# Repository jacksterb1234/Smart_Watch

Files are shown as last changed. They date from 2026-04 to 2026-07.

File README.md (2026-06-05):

# Smart Watch — Custom KiCad Smartwatch PCB

A fully custom smartwatch designed from the ground up, featuring a purpose-built PCB, BLE connectivity, and a 3D-printed case. Designed for complete control over hardware and software integration.

> Integration testing projected to begin July 2026.

## Features

- **MCU:** Nordic nRF54L15 — ultra-low power with integrated Bluetooth LE
- **Step counting** via IMU
- **Heart rate sensing**
- **Touchscreen display**
- **Music control** and **notification vibration** (haptic)
- **USB-C charging**
- **Custom 3D-printed case** — ~30% lighter than off-the-shelf alternatives, fully personalizable
- Designed for **JLCPCB assembly**

## Repository Structure

```
Smart_Watch/
├── Architecture.kicad_sch   # Top-level architecture schematic
├── MCU.kicad_sch            # nRF54L15 MCU schematic
├── Power.kicad_sch          # Power management schematic
├── Peripherals.kicad_sch   # Sensors & peripheral schematic
├── Smart_Watch.kicad_pcb   # PCB layout
├── Smart_Watch.pdf          # Full schematic export
├── Smart_Watch.pretty/     # Custom KiCad footprints
├── Smart_Watch.3dshapes/   # 3D models for PCB components
├── ZIF.pretty/              # ZIF connector footprints
├── B2B_PH_SM4_TB/          # Board-to-board connector footprints
├── Backpack_Board/         # Backpack extension board
├── Case/                   # 3D-printable case files
└── jlcpcb/                  # JLCPCB production files (Gerbers, BOM, CPL)
```

## Tools Used

- **KiCad** — Schematic capture and PCB layout
- **JLCPCB** — PCB fabrication and SMT assembly
- **SolidWorks / Fusion360** — Case design

## Key Components

| Component | Function |
|---|---|
| nRF54L15 | MCU with integrated BLE |
| Heart rate sensor | Optical heart rate monitoring |
| IMU | Step counting and motion sensing |
| Touchscreen | User interface display |
| USB-C charger IC | Battery charging via USB-C |

## Author

**Jackson Barber** — [github.com/jacksterb1234](https://github.com/jacksterb1234)

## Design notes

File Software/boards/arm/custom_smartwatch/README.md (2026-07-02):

# Custom Smartwatch Board

Initial Zephyr board definition for the NORA-B106 / nRF5340 application core.
Pin mappings use the local KiCad NORA-B106 symbol and preserve the same
schematic net distribution used before the module swap.

Build from the application root with the NCS v3.3.1 toolchain environment:

```powershell
$tc = 'C:\ncs\toolchains\936afb6332'
$env:PATH = "$tc;$tc\mingw64\bin;$tc\bin;$tc\opt\bin;$tc\opt\bin\Scripts;$tc\opt\nanopb\generator-bin;$tc\nrfutil\bin;$tc\opt\zephyr-sdk\arm-zephyr-eabi\bin;$tc\opt\zephyr-sdk\riscv64-zephyr-elf\bin;$env:PATH"
$env:PYTHONPATH = "$tc\opt\bin;$tc\opt\bin\Lib;$tc\opt\bin\Lib\site-packages"
$env:NRFUTIL_HOME = "$tc\nrfutil\home"
$env:ZEPHYR_TOOLCHAIN_VARIANT = 'zephyr'
$env:ZEPHYR_SDK_INSTALL_DIR = "$tc\opt\zephyr-sdk"
$env:ZEPHYR_BASE = 'C:\ncs\v3.3.1\zephyr'
west build --sysbuild -b custom_smartwatch/nrf5340/cpuapp -- -DBOARD_ROOT="$PWD"
```

Track bring-up and product readiness in the
[firmware readiness checklist](../../../docs/firmware_readiness_checklist.md).

The board currently enables the main I2C bus, nPM1300, BMI270, LPS22DF, four
buttons, GC9A01 display SPI, W25Q32 QSPI flash, FAN5622 backlight GPIO, and
DRV2603 haptic PWM/enable pins where Zephyr has suitable upstream bindings. The
sysbuild path also builds the nRF5340 network-core `ipc_radio` image for BLE
HCI IPC.

The nPM1300 charger profile is configured for a single-cell LiPo with 4.2 V
termination, 200 mA charge current, 3.7 V nominal voltage, and no thermistor.

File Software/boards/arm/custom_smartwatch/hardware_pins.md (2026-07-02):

# Custom Smartwatch Pin Ledger

This ledger records schematic net names against NORA-B106 module pads and the
local KiCad NORA-B106 symbol GPIO mapping.

## Blocking Checks

- Per user direction, the main I2C routing is corrected. Firmware maps NORA pad
  `A3` / `P1.03` as SCL and pad `B4` / `P1.02` as SDA.
- MAX30102 is represented on I2C at `0x57` using Zephyr's upstream
  `maxim,max30101` red/IR driver path. Its active-low interrupt net is on
  `P0.21`.

## Main I2C

| Signal | NORA pad | nRF5340 GPIO | Zephyr pinctrl |
| --- | --- | --- | --- |
| `SCL` | `A3` | `P1.03` | `NRF_PSEL(TWIM_SCL, 1, 3)` |
| `SDA` | `B4` | `P1.02` | `NRF_PSEL(TWIM_SDA, 1, 2)` |

Shared by BMI270, MAX30102, LPS22DF, nPM1300, and display touch I2C.

## Interrupts

| Net | NORA pad | nRF5340 GPIO | Firmware status |
| --- | --- | --- | --- |
| `PMIC_INT` | `H1` | `P0.24` | Enabled |
| `BMI_INT` | `C8` | `P0.22` | Enabled |
| `MAX_INT` | `E3` | `P0.21` | Enabled via MAX30101-compatible driver |
| `LPS_INT` | `A5` | `P0.20` | Enabled |

## Buttons

All buttons are active-low to ground and should use pull-ups.

| Switch | Net | NORA pad | nRF5340 GPIO |
| --- | --- | --- | --- |
| `SW4` | `BTN_1` | `G2` | `P0.26` |
| `SW5` | `BTN_2` | `B5` | `P0.03` |
| `SW6` | `BTN_3` | `A4` | `P1.00` |
| `SW7` | `BTN_4` | `F8` | `P1.14` |

## Display SPI And Control

| Net | NORA pad | nRF5340 GPIO |
| --- | --- | --- |
| `DISPLAY_CS` | `A2` | `P0.12` |
| `DISPLAY_CLK` | `B3` | `P0.11` |
| `DISPLAY_DATA` | `C1` | `P0.10` |
| `DISPLAY_DC` | `C2` | `P0.09` |
| `DISPLAY_RST` | `J9` | `P0.31` |

## Display Touch And Backlight

| Net | NORA pad | nRF5340 GPIO |
| --- | --- | --- |
| `CTP_INT` | `B1` | `P0.08` |
| `CTP_RST` | `E8` | `P0.05` |
| `TOUCH_EN` | `D8` | `P0.04` |
| `DISPLAY_LIGHT_IO` | `G3` | `P0.25` |

## External Flash

| Net | NORA pad | nRF5340 GPIO |
| --- | --- | --- |
| `QSPI_IO2` | `D1` | `P0.15` |
| `QSPI_IO0` | `D2` | `P0.13` |
| `QSPI_CS` | `E1` | `P0.18` |
| `QSPI_IO1` | `E2` | `P0.14` |
| `QSPI_CLK` | `F1` | `P0.17` |
| `QSPI_IO3` | `F2` | `P0.16` |

## Haptic And Backlight

| Net | NORA pad | nRF5340 GPIO |
| --- | --- | --- |
| `LRA_PWM` | `H7` | `P0.29` |
| `LRA_EN` | `J8` | `P0.28` |
| `DISPLAY_LIGHT_IO` | `G3` | `P0.25` |

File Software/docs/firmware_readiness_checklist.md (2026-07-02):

# Firmware Readiness Checklist

This checklist is the source of truth for getting the custom smartwatch from
board definition to useful firmware. When every item is complete, the firmware
should flash to the NORA-B106/nRF5340 board, pair with a phone, control phone
music, track steps, and report heart rate.

Assumption: "play music" means Bluetooth LE media control of phone playback. It
does not mean audio playback or streaming from the watch hardware.

## Current Baseline

- [x] Custom Zephyr board target exists for `custom_smartwatch/nrf5340/cpuapp`.
- [x] Board definition builds successfully with NCS v3.3.1.
- [x] Main I2C bus is mapped for nPM1300, BMI270, LPS22DF, and MAX30102 support.
- [x] PMIC, BMI270, LPS22DF, and MAX30102 interrupt GPIOs are represented.
- [x] Four user buttons are mapped through `gpio-keys`.
- [x] GC9A01 display SPI bus is represented.
- [x] W25Q32 QSPI flash is represented.
- [x] FAN5622 display backlight control GPIO is represented.
- [x] DRV2603 haptic PWM output is represented.
- [x] DRV2603 `LRA_EN` GPIO is represented as `haptic-en`.
- [x] DRV2603 `LRA_EN` and PWM are managed by a non-blocking haptics module.
- [x] FAN5622 backlight GPIO is managed by firmware as simple on/off control for bring-up.
- [x] Minimal firmware logs core device readiness.
- [x] Hardware pin ledger uses NORA-B106/nRF5340 terminology.
- [x] RTT logging and console backend are configured for board bring-up.
- [x] nRF5340 network-core `ipc_radio` target builds through sysbuild.
- [x] Basic BLE HID Consumer Control service is implemented for phone media keys.
- [x] Button events are deferred through static work and mapped to media actions.
- [x] Basic BMI270 step tracking is implemented through Zephyr Sensor API scheduled work.
- [x] Step totals are persisted through Zephyr settings/NVS with throttled writes.
- [x] Basic GC9A01 display UI renders BLE state, step count, heart-rate status, and live battery/USB state.
- [x] MAX30102 is represented using Zephyr's upstream `maxim,max30101` red/IR driver path.
- [x] SW7 starts a bounded MAX30102 heart-rate measurement.
- [x] nPM1300 charger profile is configured for a 4.2 V, 200 mA, no-thermistor single-cell LiPo.
- [x] nPM1300 battery voltage/current/USB telemetry is sampled through the upstream charger driver.
- [x] BLE Battery Service level is updated from the nPM1300 voltage estimate.
- [x] Simple user settings are persisted through Zephyr settings/NVS.
- [x] Display-off power state blanks the GC9A01 and disables the backlight after a persisted timeout.
- [x] Current app code has been checked for no `malloc`/`free`, no `printf`, no polling main loop, and no blocking sleep calls.

## Before First Useful Flash

- [x] Add a reliable board bring-up logging path, preferably RTT.
- [ ] Confirm `west flash` runner behavior with the selected debug probe.
- [ ] Verify first boot logs on hardware.
- [ ] Verify nPM1300 responds on I2C and reports charger/battery state.
- [ ] Verify BMI270 responds on I2C and produces accelerometer samples.
- [ ] Verify LPS22DF responds on I2C and produces pressure/temperature samples.
- [ ] Verify W25Q32 JEDEC ID, erase, write, and read through QSPI.
- [ ] Verify GC9A01 display initialization with a visible test pattern.
- [ ] Verify FAN5622 behavior and replace generic GPIO handling if brightness requires pulse control.
- [ ] Verify all four buttons generate input events with the expected active-low polarity.
- [ ] Verify DRV2603 enable plus PWM produces controlled haptic output.
- [x] Add Bluetooth LE support for nRF5340 using sysbuild so the network-core controller image is included.
- [x] Add MAX30102 support using the upstream MAX30101-compatible Zephyr Sensor API driver.
- [ ] Confirm the MAX30102 part ID matches the upstream driver's expected ID on real hardware.

## Product Firmware

- [x] Add a static button service that maps SW4 to play/pause, SW5 to next, SW6 to previous, and SW7 to screen cycle or heart-rate check.
- [x] Add Bluetooth pairing, bonding, reconnect, and HID-over-GATT Consumer Control media keys.
- [x] Add a baseline display UI for BLE status, step count, heart-rate placeholder, and battery/charge placeholder.
- [x] Replace battery/charge display placeholder with live nPM1300 telemetry.
- [x] Replace heart-rate display placeholder with live MAX30102 measurement status and BPM when available.
- [x] Add BMI270 step tracking using Zephyr Sensor API data and interrupt/workqueue processing.
- [x] Add MAX30102 heart-rate sampling with no-finger and poor-signal handling.
- [ ] Tune MAX30102 LED current, thresholds, and BPM filtering on real wrist/finger data.
- [x] Add haptic feedback patterns using `LRA_EN` and PWM without blocking delays.
- [x] Add persistent storage for Bluetooth bonding/settings data.
- [x] Add persistent storage for step totals.
- [x] Add persistent storage for simple user settings.
- [x] Add nPM1300 charger and battery telemetry reporting.
- [ ] Add nPM1300 regulator rail diagnostics if hardware bring-up shows they are needed.
- [x] Confirm battery charge current, termination voltage, and thermistor setup before enabling nPM1300 charging.
- [x] Add display-off power state with button wake and persisted timeout.
- [ ] Add sensor idle, BLE connected idle, and deep-sleep states after first current measurements.
- [x] Audit app code for no dynamic allocation, no `printf`, no polling main loop, and no blocking delays in steady-state behavior.

## Acceptance Tests

- [x] `west build --sysbuild -b custom_smartwatch/nrf5340/cpuapp -- -DBOARD_ROOT="$PWD"` passes cleanly.
- [ ] `west flash` programs both nRF5340 application and network cores.
- [ ] Boot log reports PMIC, BMI270, LPS22DF, display, flash, buttons, haptic PWM, haptic enable, and MAX30102 readiness or clear failure state.
- [ ] Phone pairs over Bluetooth LE and the watch controls media playback.
- [ ] Button mapping matches the intended default controls.
- [ ] Step count increases during walking or repeatable motion testing and persists across reboot.
- [ ] Heart-rate screen produces BPM readings with clear handling for no-finger/poor-signal cases.
- [ ] Display renders the normal UI, backlight control works, and haptic feedback fires on expected events.
- [ ] Sleep/display-off current is measured and recorded as a regression target.

## Build References

Current board-only build:

```powershell
west build --pristine=always -b custom_smartwatch/nrf5340/cpuapp -- -DBOARD_ROOT="$PWD"
```

Final flash-ready build target:

```powershell
west build --sysbuild -b custom_smartwatch/nrf5340/cpuapp -- -DBOARD_ROOT="$PWD"
```

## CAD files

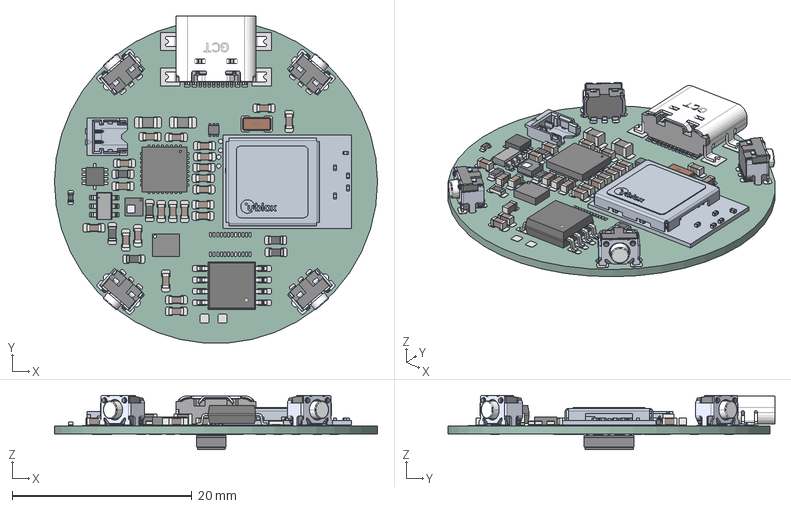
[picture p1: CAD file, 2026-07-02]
Case/Main_Board_V5.step
36.0 x 36.4 x 6.03 mm
C_0603 x 22
SKRTLAE010 x 4
R_0402
L_0805_2012Metric x 2
R_0603 x 6
UDFN6_517AA_ONS
Main_Board_V5 1.12.1
Main_Board_V5 1.12.2
Main_Board_V5 1.12.3
Main_Board_V5 1.12.4
Main_Board_V5 1.12.5
Main_Board_V5 1.12.6
Main_Board_V5 1.12.7
Main_Board_V5 1.12.8
Main_Board_V5 1.12.9
Main_Board_V5 1.12.10
Main_Board_V5 1.12.11
Main_Board_V5 1.12.12
Main_Board_V5 1.12.13
Main_Board_V5 1.12.14
Main_Board_V5 1.12.15
Main_Board_V5 1.12.16
Main_Board_V5 1.12.17
Main_Board_V5 1.12.18
Main_Board_V5 1.12.19
Main_Board_V5 1.12.20
Main_Board_V5 1.12.21
Main_Board_V5 1.12.22
Main_Board_V5 1.12.23
Main_Board_V5 1.12.24
Main_Board_V5 1.12.25
Main_Board_V5 1.12.26
Main_Board_V5 1.12.27
Main_Board_V5 1.12.28
Main_Board_V5 1.12.29
Main_Board_V5 1.12.30
Main_Board_V5 1.12.31
Main_Board_V5 1.12.32
Main_Board_V5 1.12.33
QFN32_5X5_NOR
PIN1_AREA
SOIC-8_5.3x5.3mm_P1.27mm
USB4110-GF-A_revB(1) MF
SSOT6_3X1P7_ONS
FC-135R_L3.2-W1.5
LPS22DFTR
BMI270
MAX30102EFD_T
Smart_Watch_pad
Smart_Watch_PCB

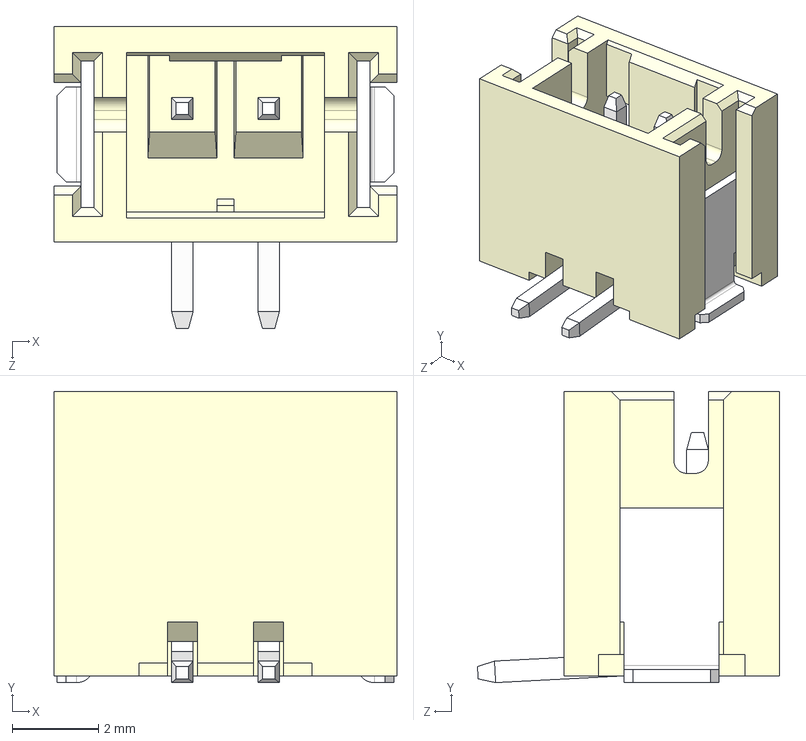
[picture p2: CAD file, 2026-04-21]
B2B_PH_SM4_TB/B2B-PH-SM4-TB.STEP
7.95 x 6.75 x 7.00 mm

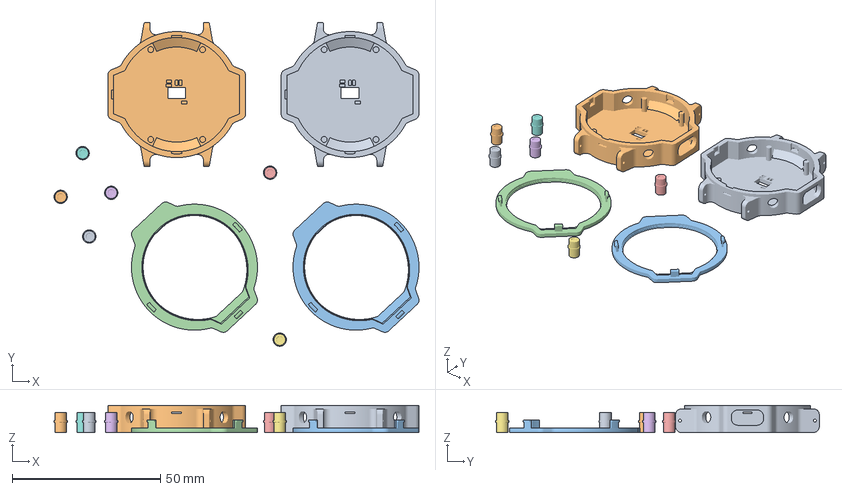
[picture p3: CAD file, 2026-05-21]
Case/Prints/Watch_Print.3mf
123.1 x 109.2 x 9.13 mm
Watch_Case.step x 2
Watch_Cap.step x 2
Watch_Button.step x 6

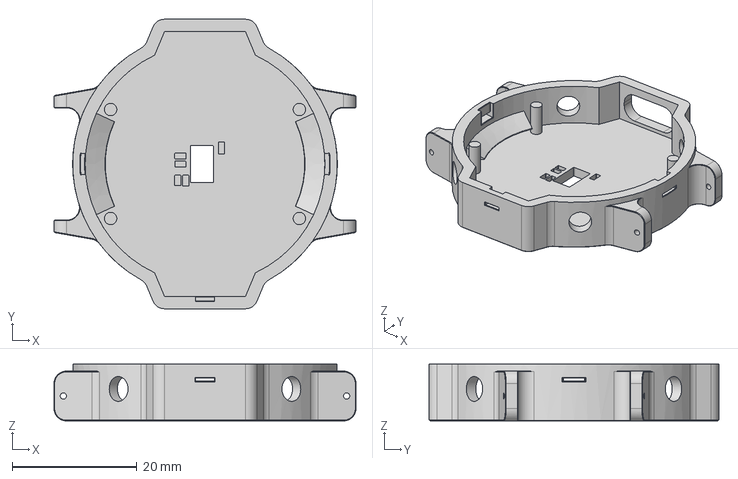
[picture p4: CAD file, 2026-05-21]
Case/Watch_Case.step
48.5 x 46.5 x 9.13 mm

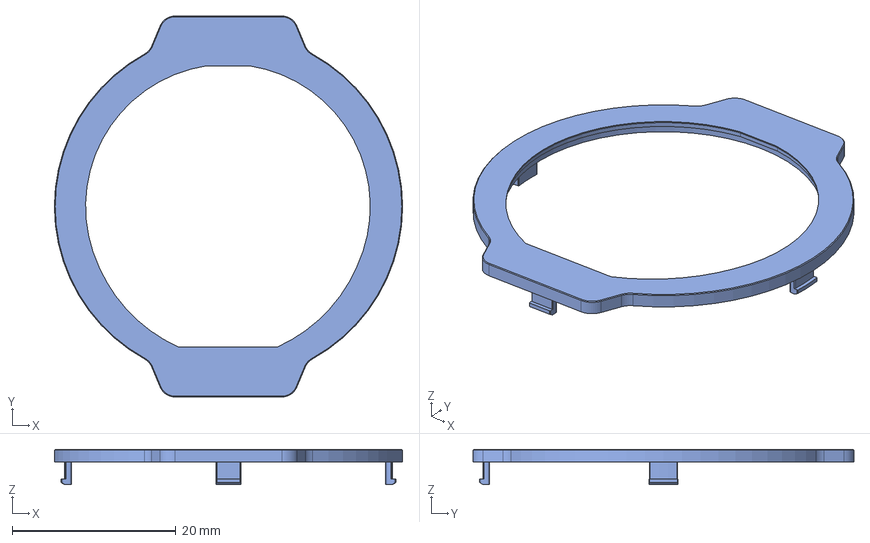
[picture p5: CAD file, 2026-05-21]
Case/Watch_Cap.step
42.5 x 46.5 x 4.30 mm

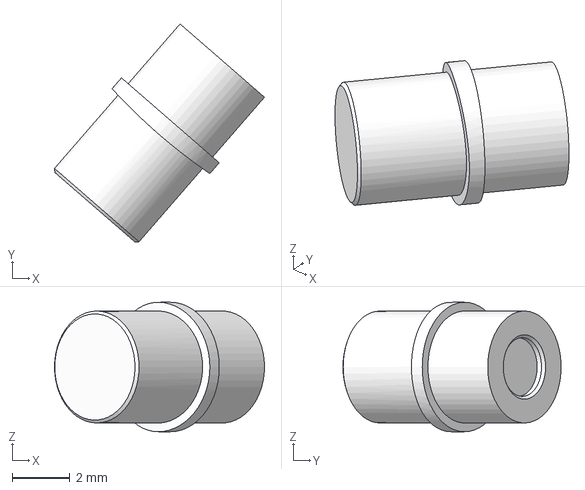
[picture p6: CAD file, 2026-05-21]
Case/Watch_Button.step
7.30 x 7.58 x 4.50 mm

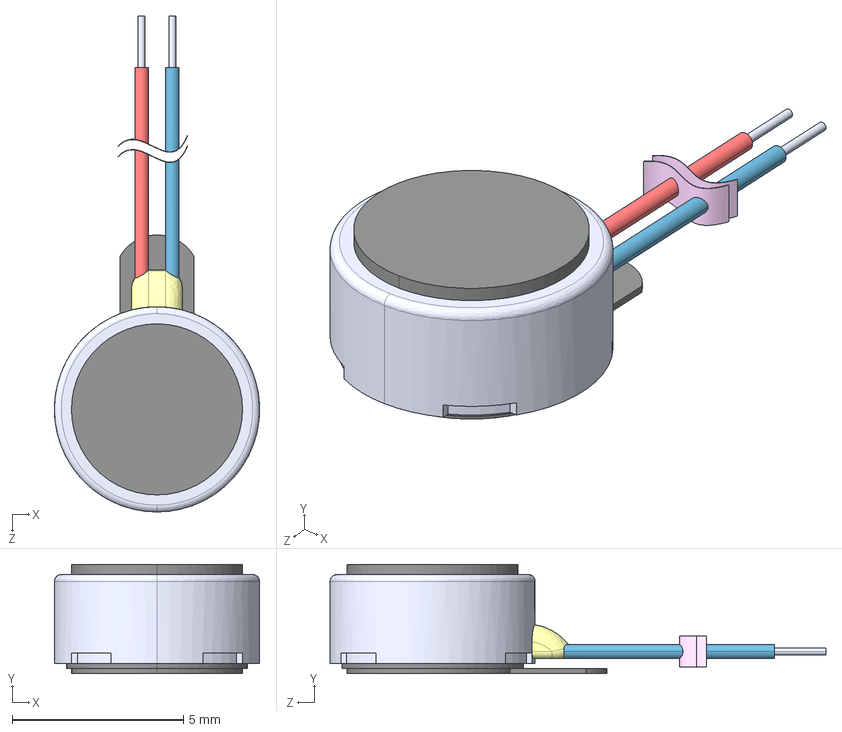
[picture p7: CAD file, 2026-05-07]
Case/HD-LA0503-LW28.step
6.00 x 3.20 x 14.5 mm

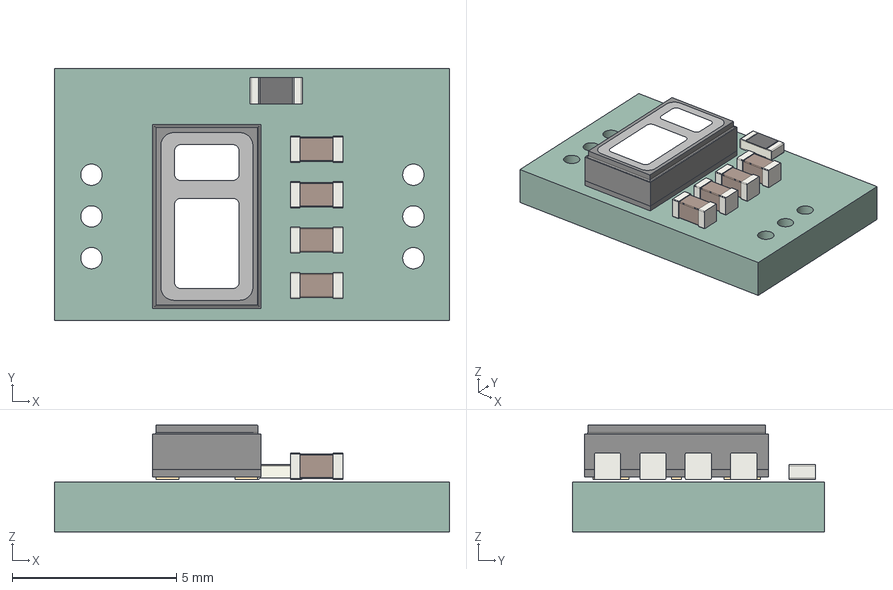
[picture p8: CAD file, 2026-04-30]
Case/Backpack_Board.step
12.0 x 7.68 x 3.25 mm
R_0603
C_0603 x 4
MAX30102EFD_T
Backpack_Board_PCB

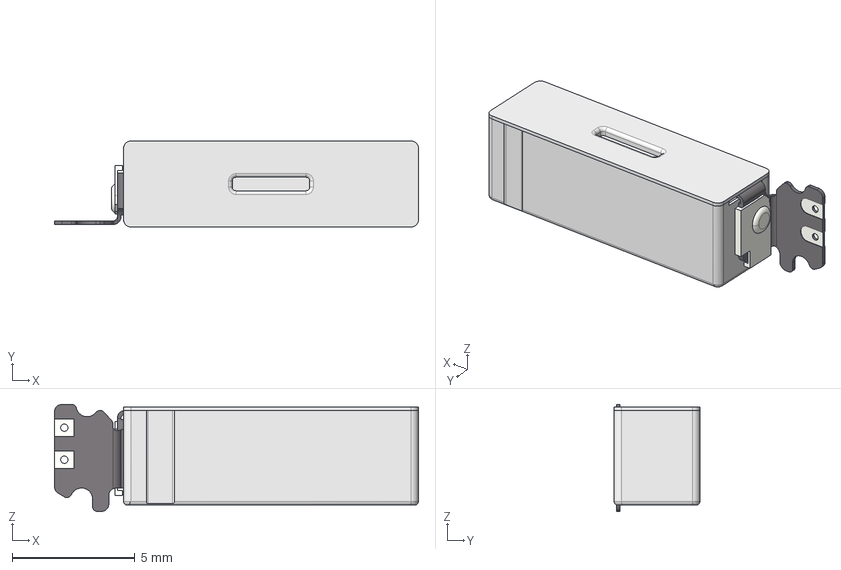
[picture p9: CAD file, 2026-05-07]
Case/VLV041235L-FP421.step
14.8 x 3.50 x 4.36 mm
SHANGJIKE_1_1_1_1_1_2_1_1_1__10
XIAJIKE_3_1_1_2_1_1_1_2_1_1_1_8
MOTOR-FPC-0326_2_1_1_1_1_1_1
GLUE-MOTOR-0629_1_1_1

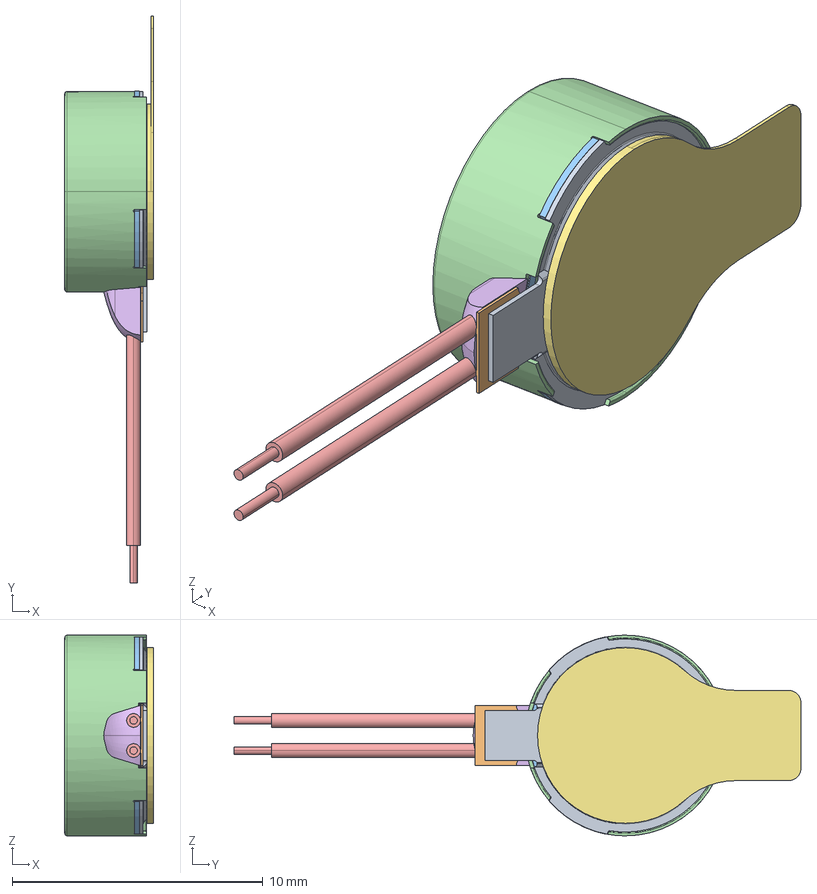
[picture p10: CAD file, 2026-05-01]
Case/VG0832013D.STEP
3.53 x 22.6 x 8.00 mm
DOWN-CASE-B1_6.stp
FPCB-FP82_6.stp
SPRING_2.stp
UP-CASE-B1_4.stp
BLUE-LEAD-WIRE_3.stp
RED-LEAD-WIRE_1.stp
UV-ADHESIVE_1.stp
000.stp

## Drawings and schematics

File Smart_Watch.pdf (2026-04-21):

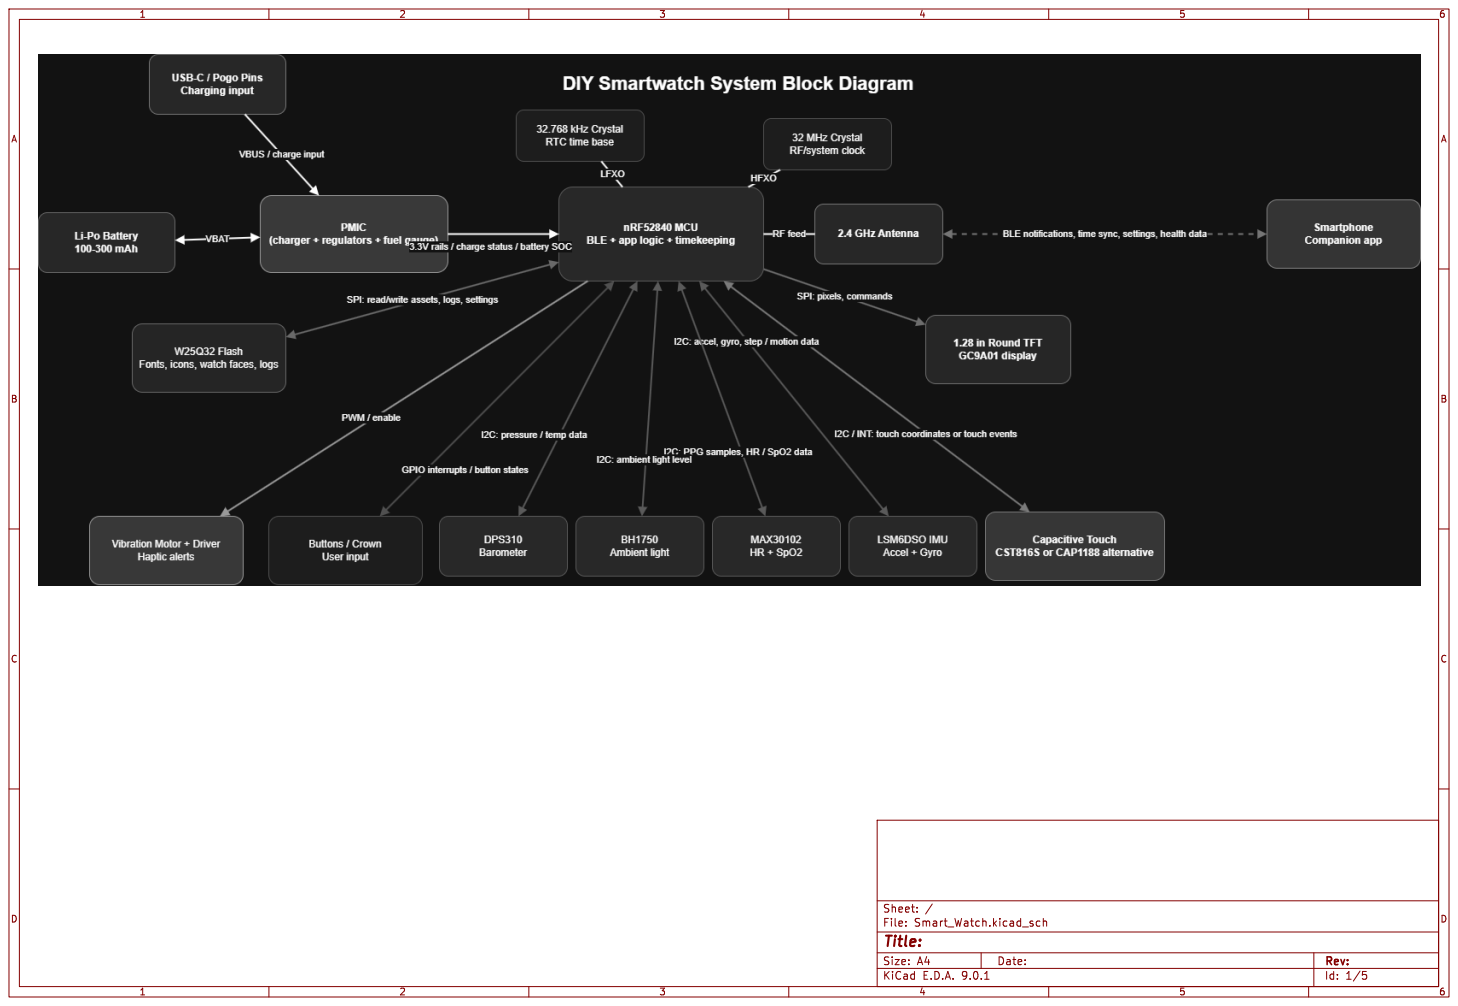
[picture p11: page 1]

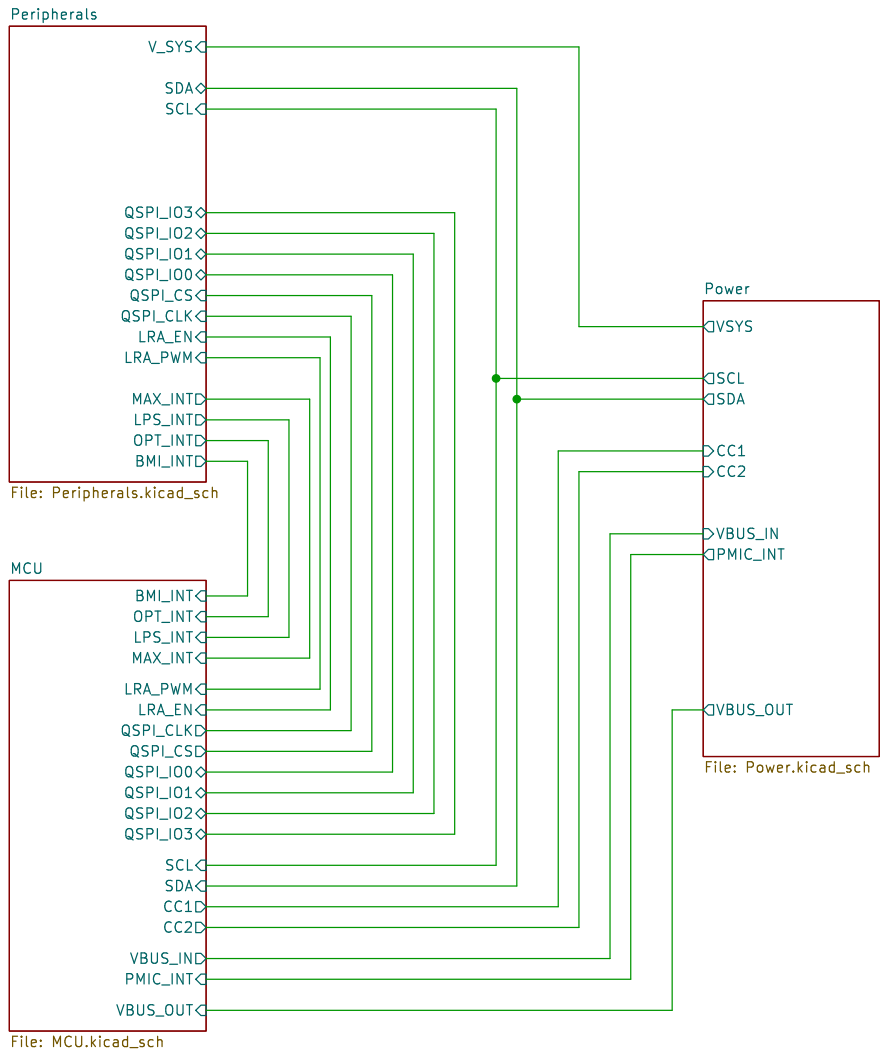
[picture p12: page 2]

Id: 2/5 Title: File: Architecture.kicad_sch Sheet: /Architecture/ CC1 CC2 PMIC_INT SCL SDA

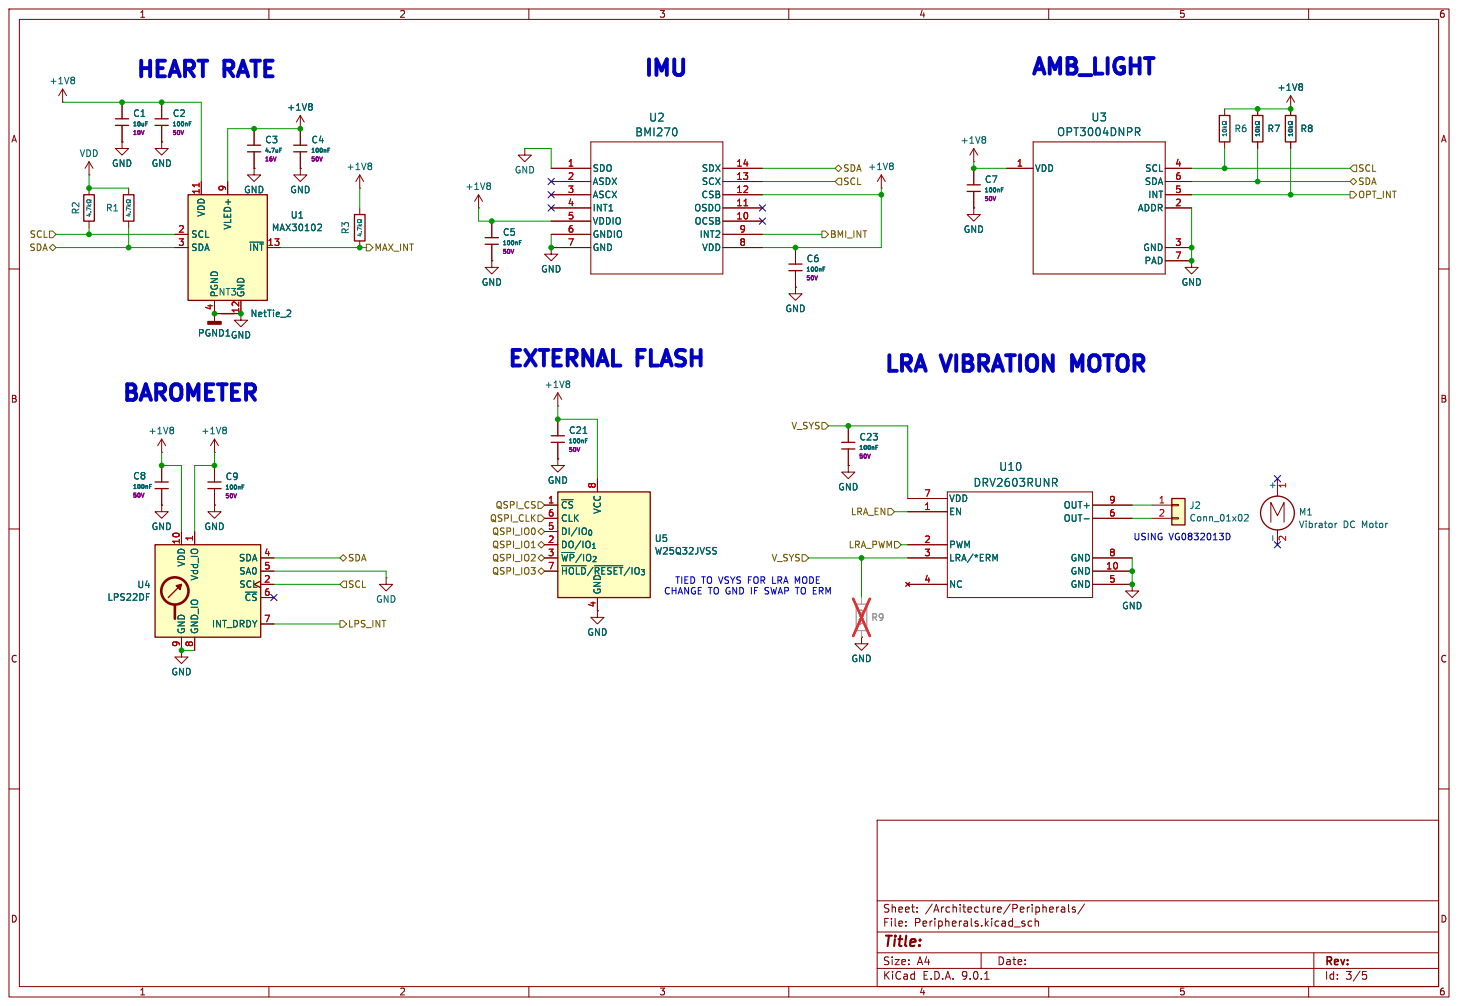
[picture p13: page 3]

INT 5 ADDR 2 GND 3 PAD 7 U3 OPT3004DNPR

TIED TO VSYS FOR LRA MODE CHANGE TO GND IF SWAP TO ERM BAROMETER

-2 M1 Vibrator DC Motor +1V8 GND

Id: 3/5 Title: File: Peripherals.kicad_sch Sheet: /Architecture/Peripherals/

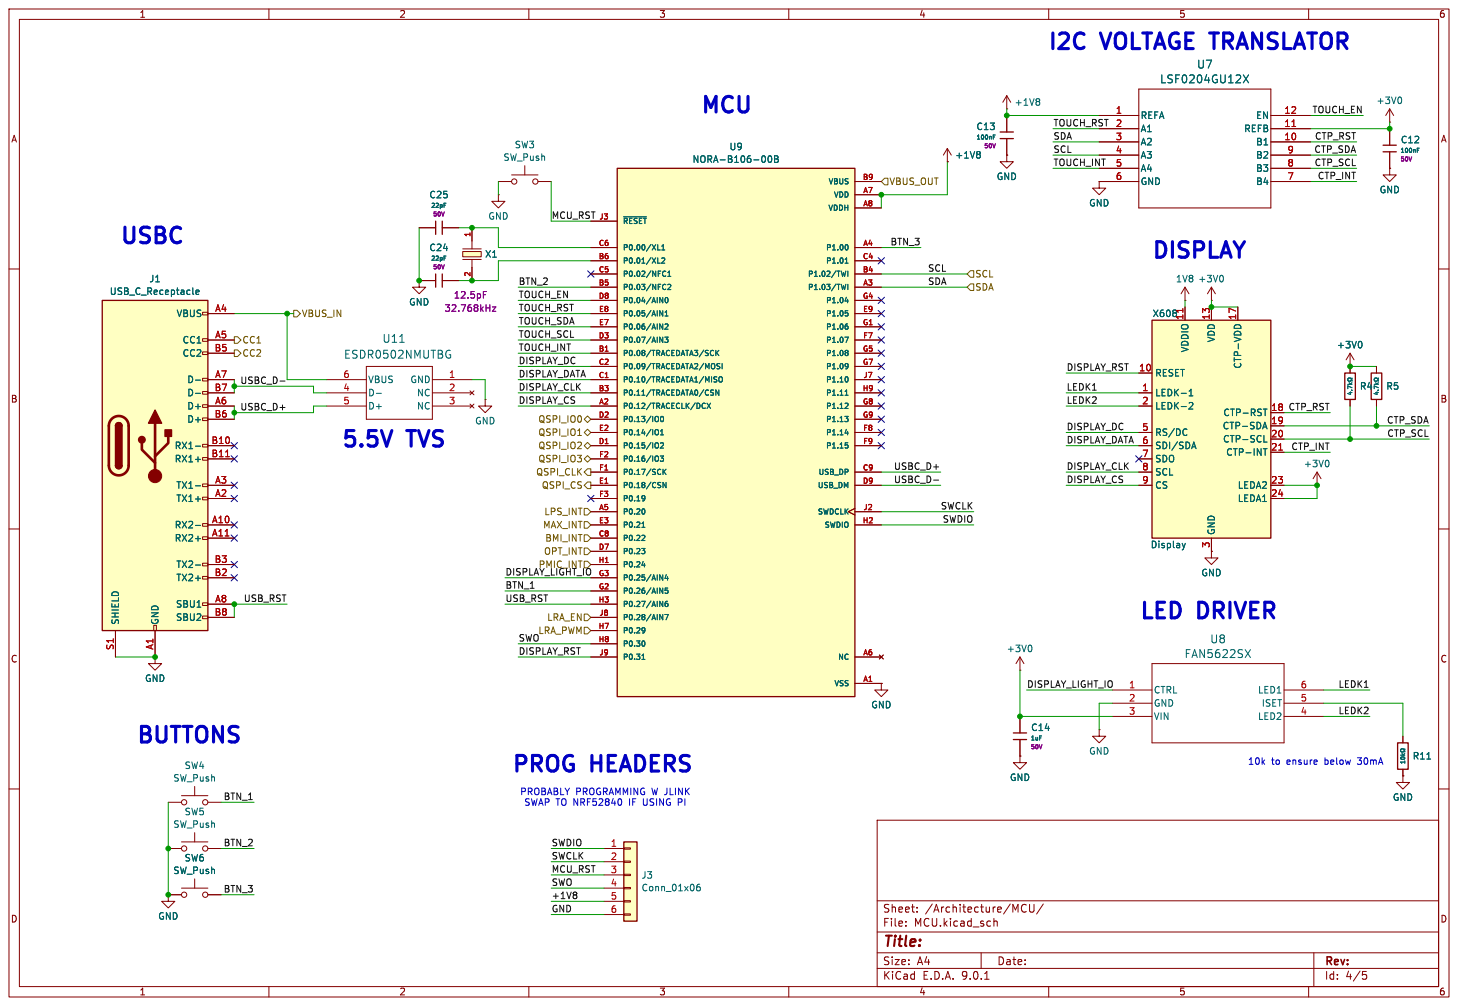
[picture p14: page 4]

10k to ensure below 30mA MCU

3 CTP-VDD 17 CTP-RST 18 CTP-SDA 19 CTP-SCL 20 CTP-INT 21

SWAP TO NRF52840 IF USING PI BUTTONS

Id: 4/5 Title: File: MCU.kicad_sch Sheet: /Architecture/MCU/

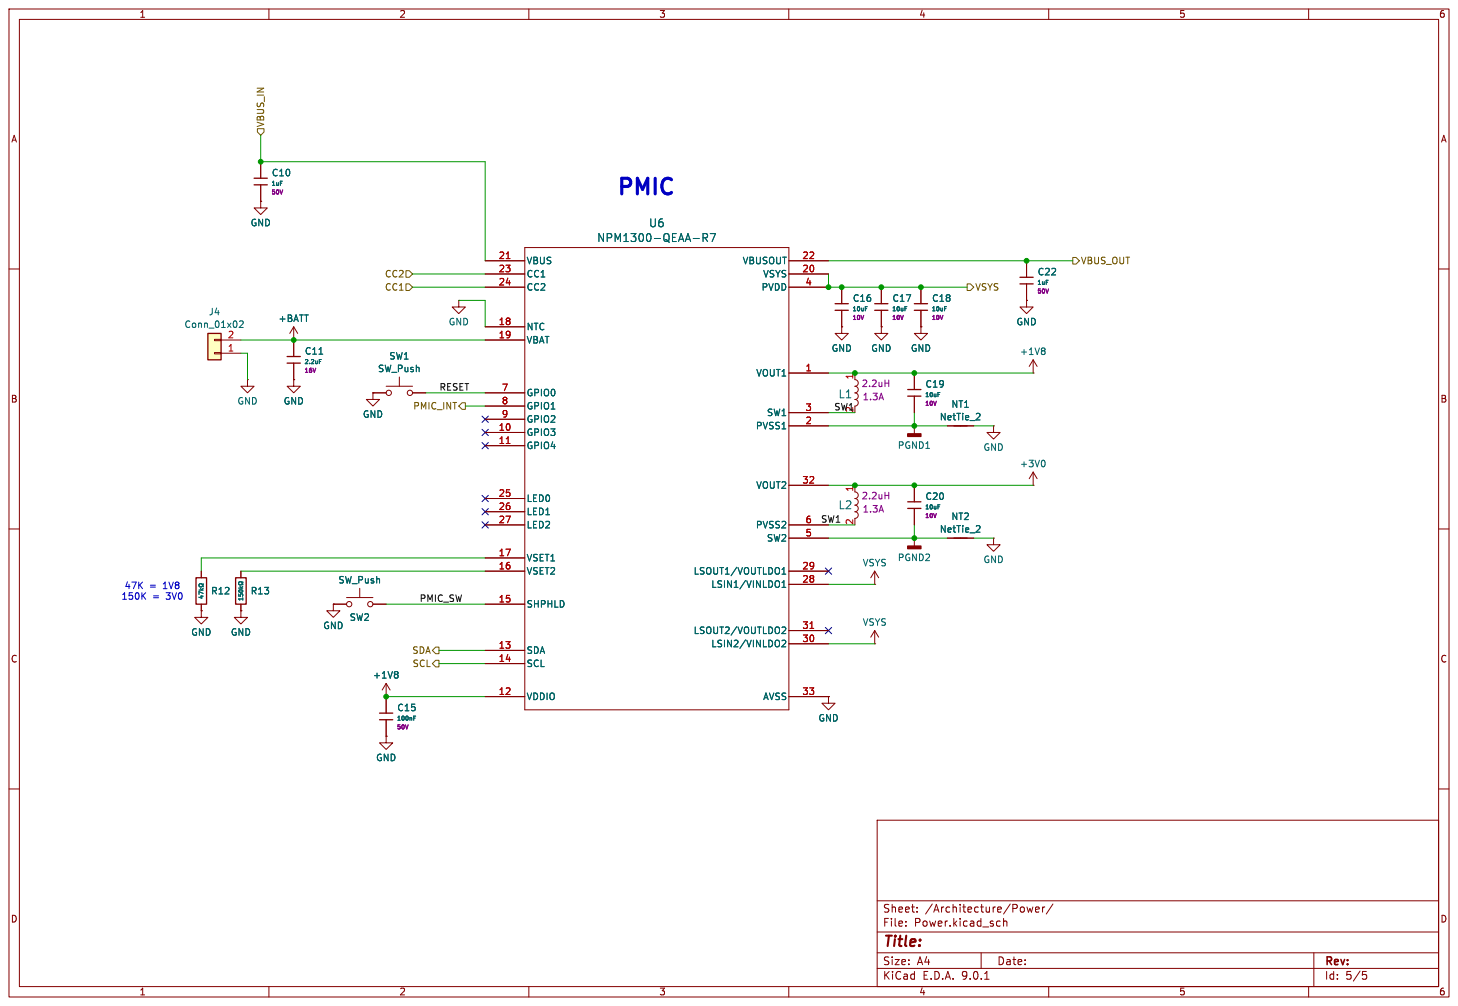
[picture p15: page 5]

Id: 5/5 Title: File: Power.kicad_sch Sheet: /Architecture/Power/

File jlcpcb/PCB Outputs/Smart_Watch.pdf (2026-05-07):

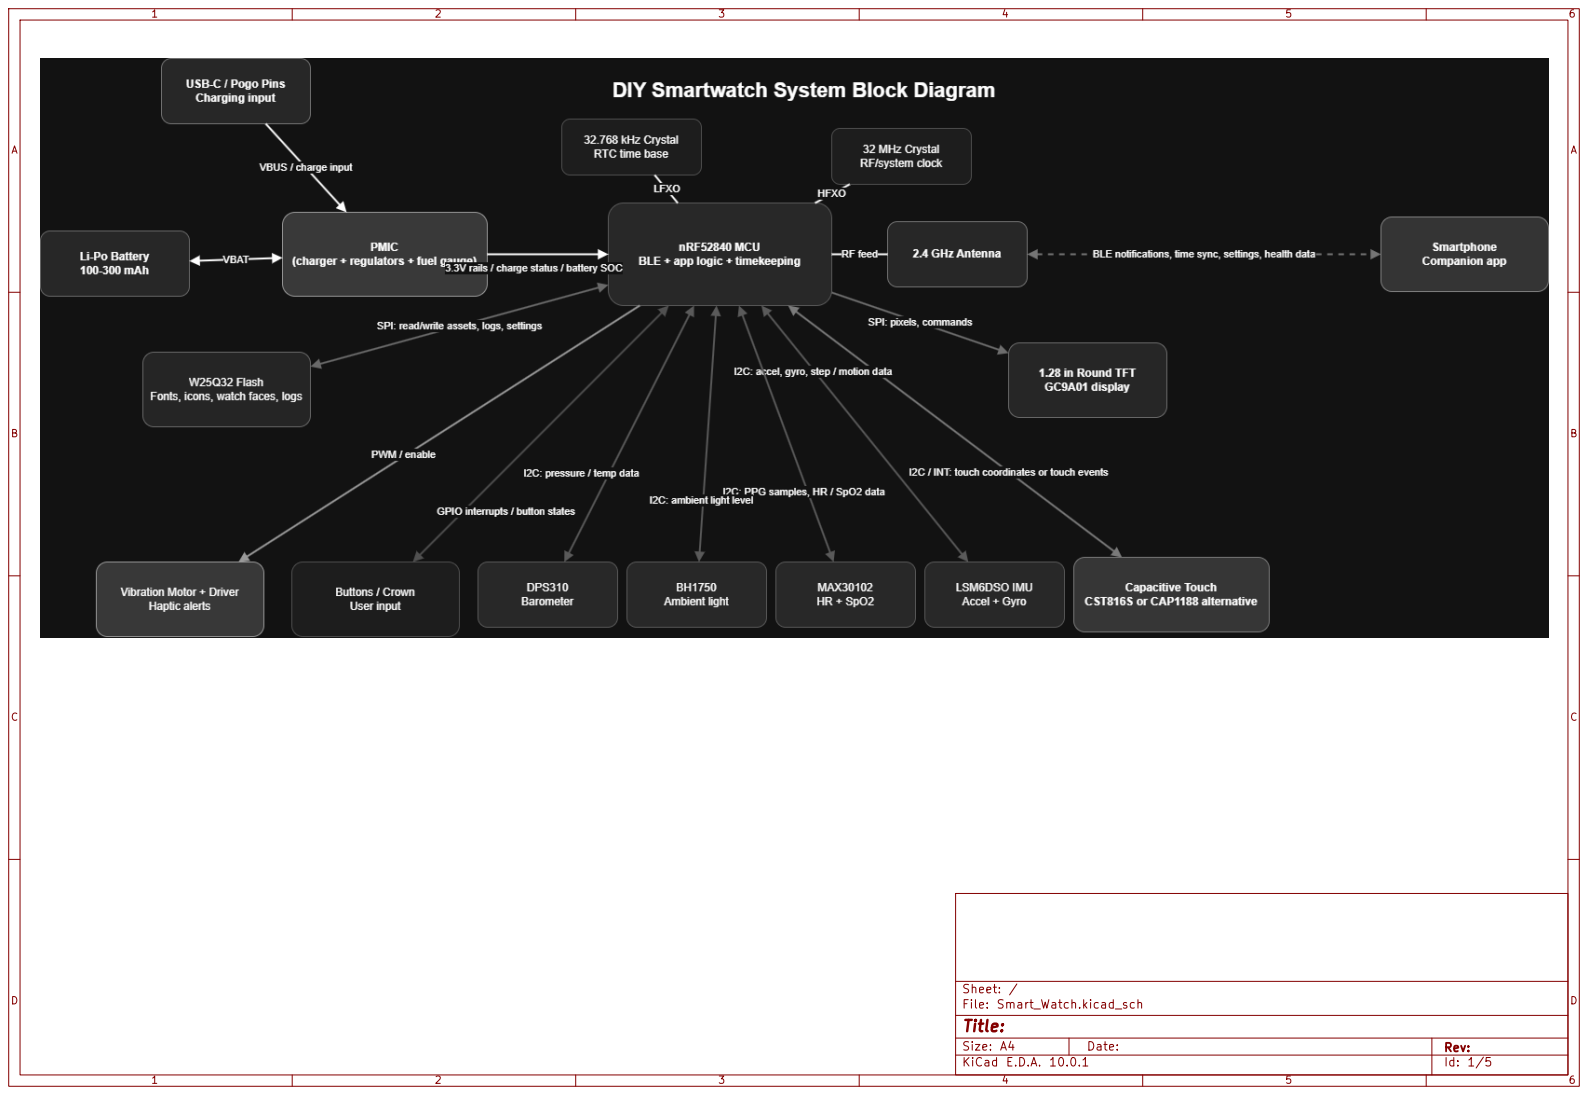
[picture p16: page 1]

Size: A4 | Rev:
KiCad E.D.A. 10.0.1 | Id: 1/5

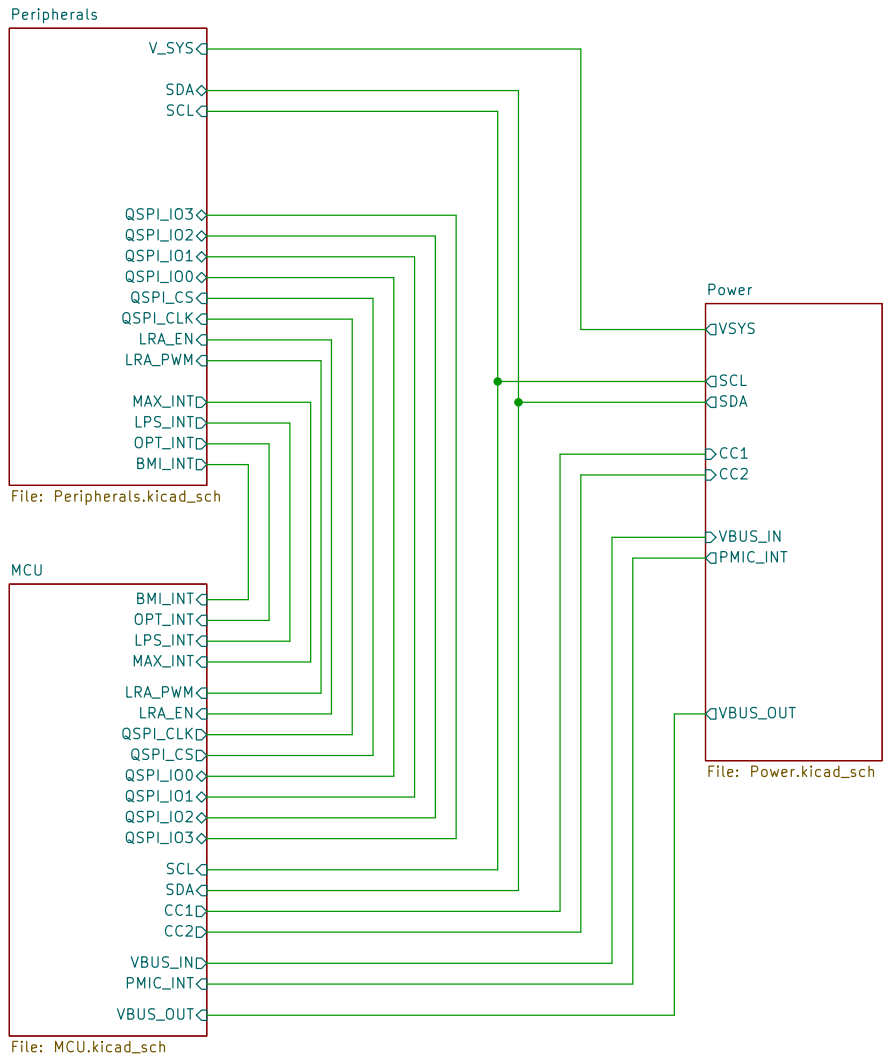
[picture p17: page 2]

VBUS_OUT VSYS Power File: Power.kicad_sch BMI_INT LPS_INT MAX_INT OPT_INT PMIC_INT QSPI_CLK QSPI_CS QSPI_IO0 QSPI_IO1 QSPI_IO2 QSPI_IO3
VBUS_OUT MCU

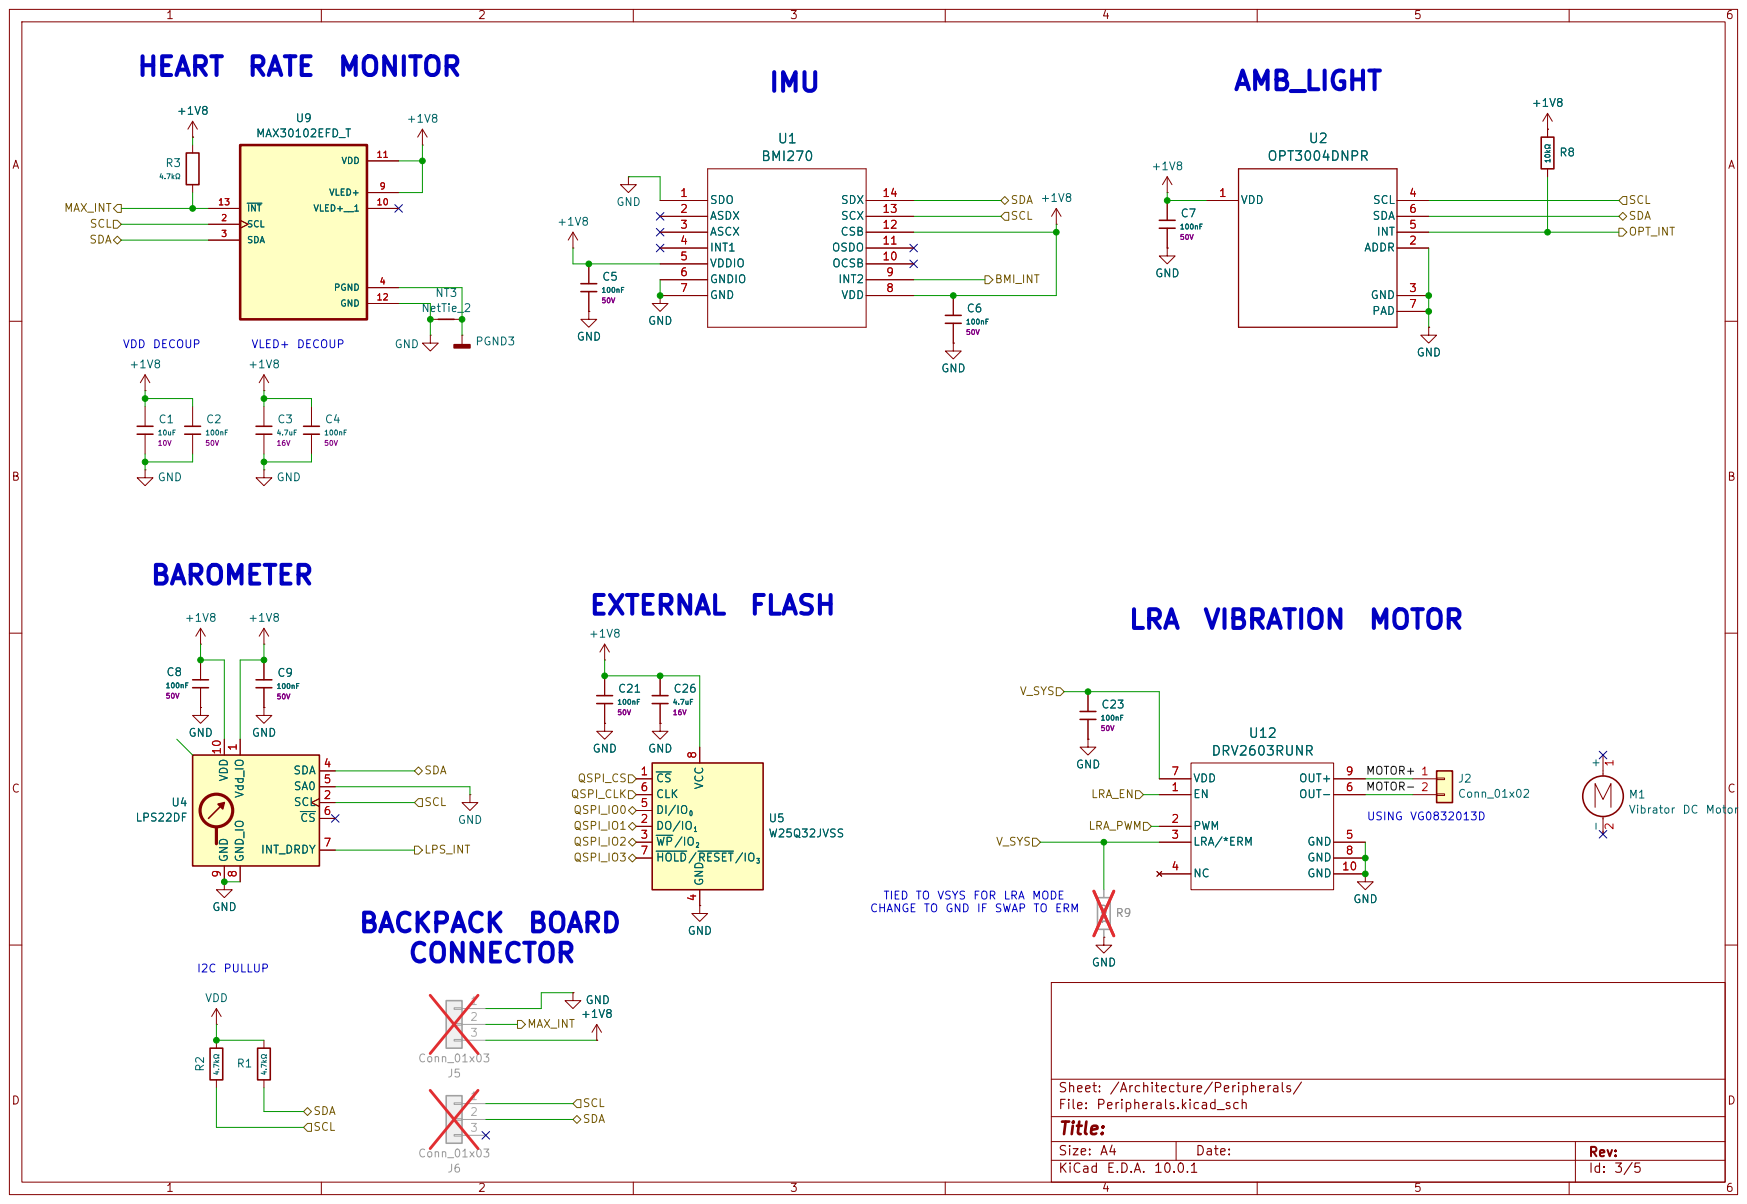
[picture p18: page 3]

4 DI/IO0 5 CLK 6 HOLD/RESET/IO3 7 VCC

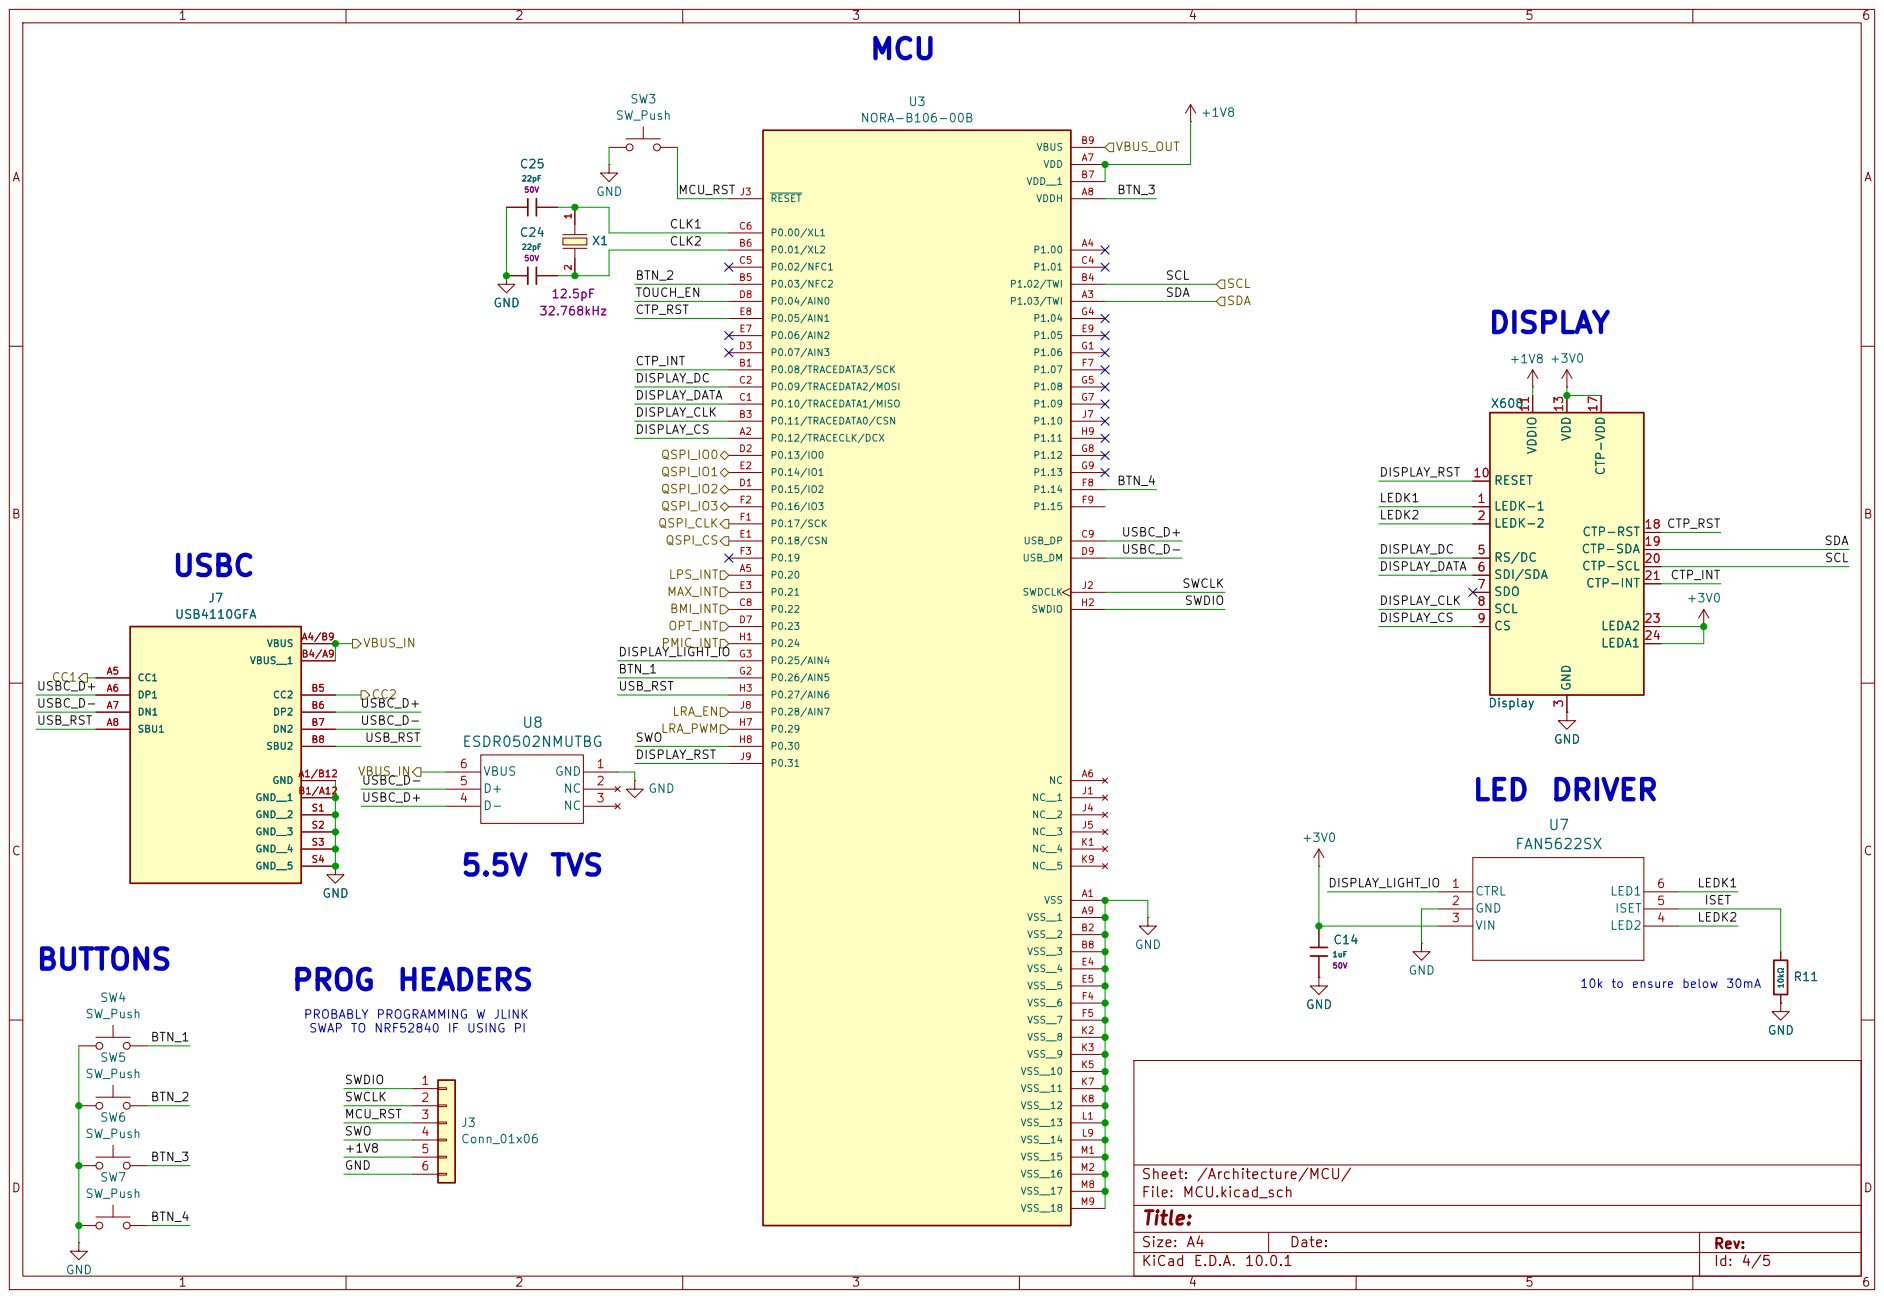
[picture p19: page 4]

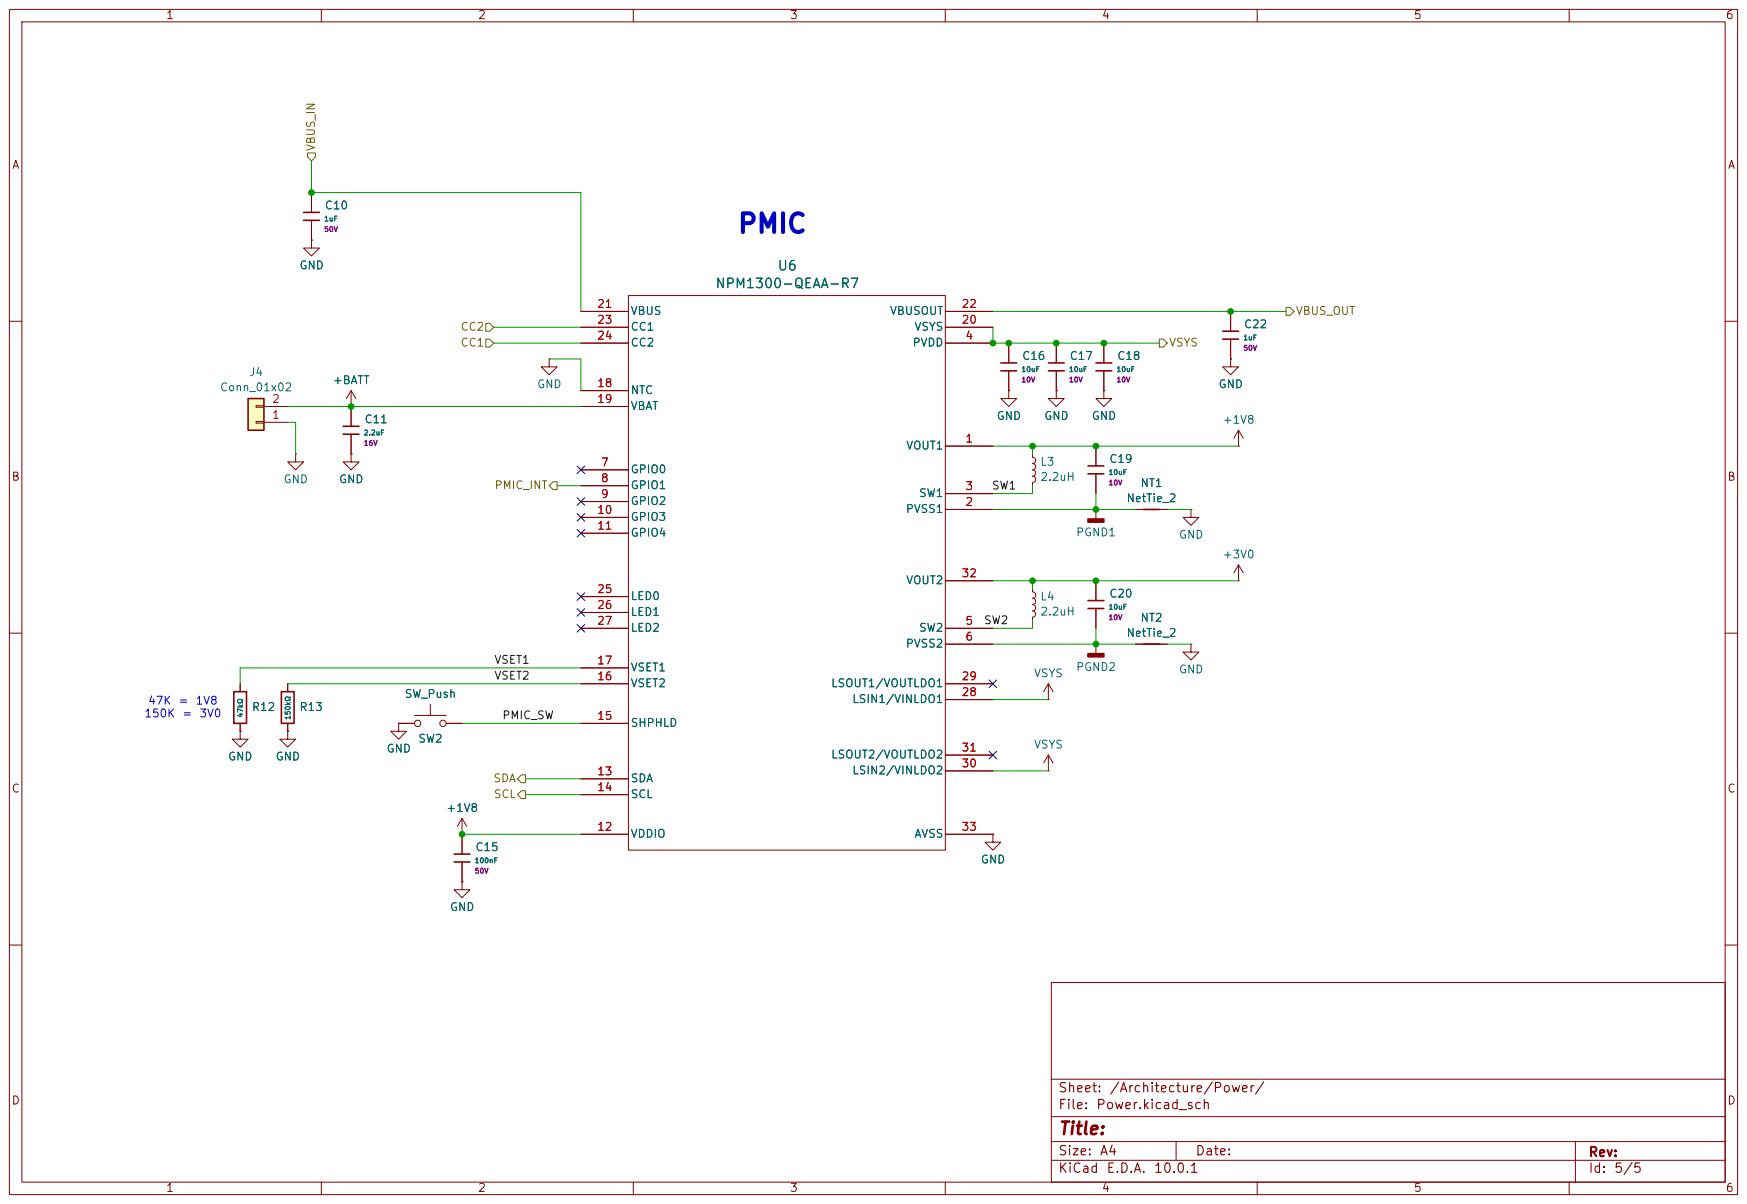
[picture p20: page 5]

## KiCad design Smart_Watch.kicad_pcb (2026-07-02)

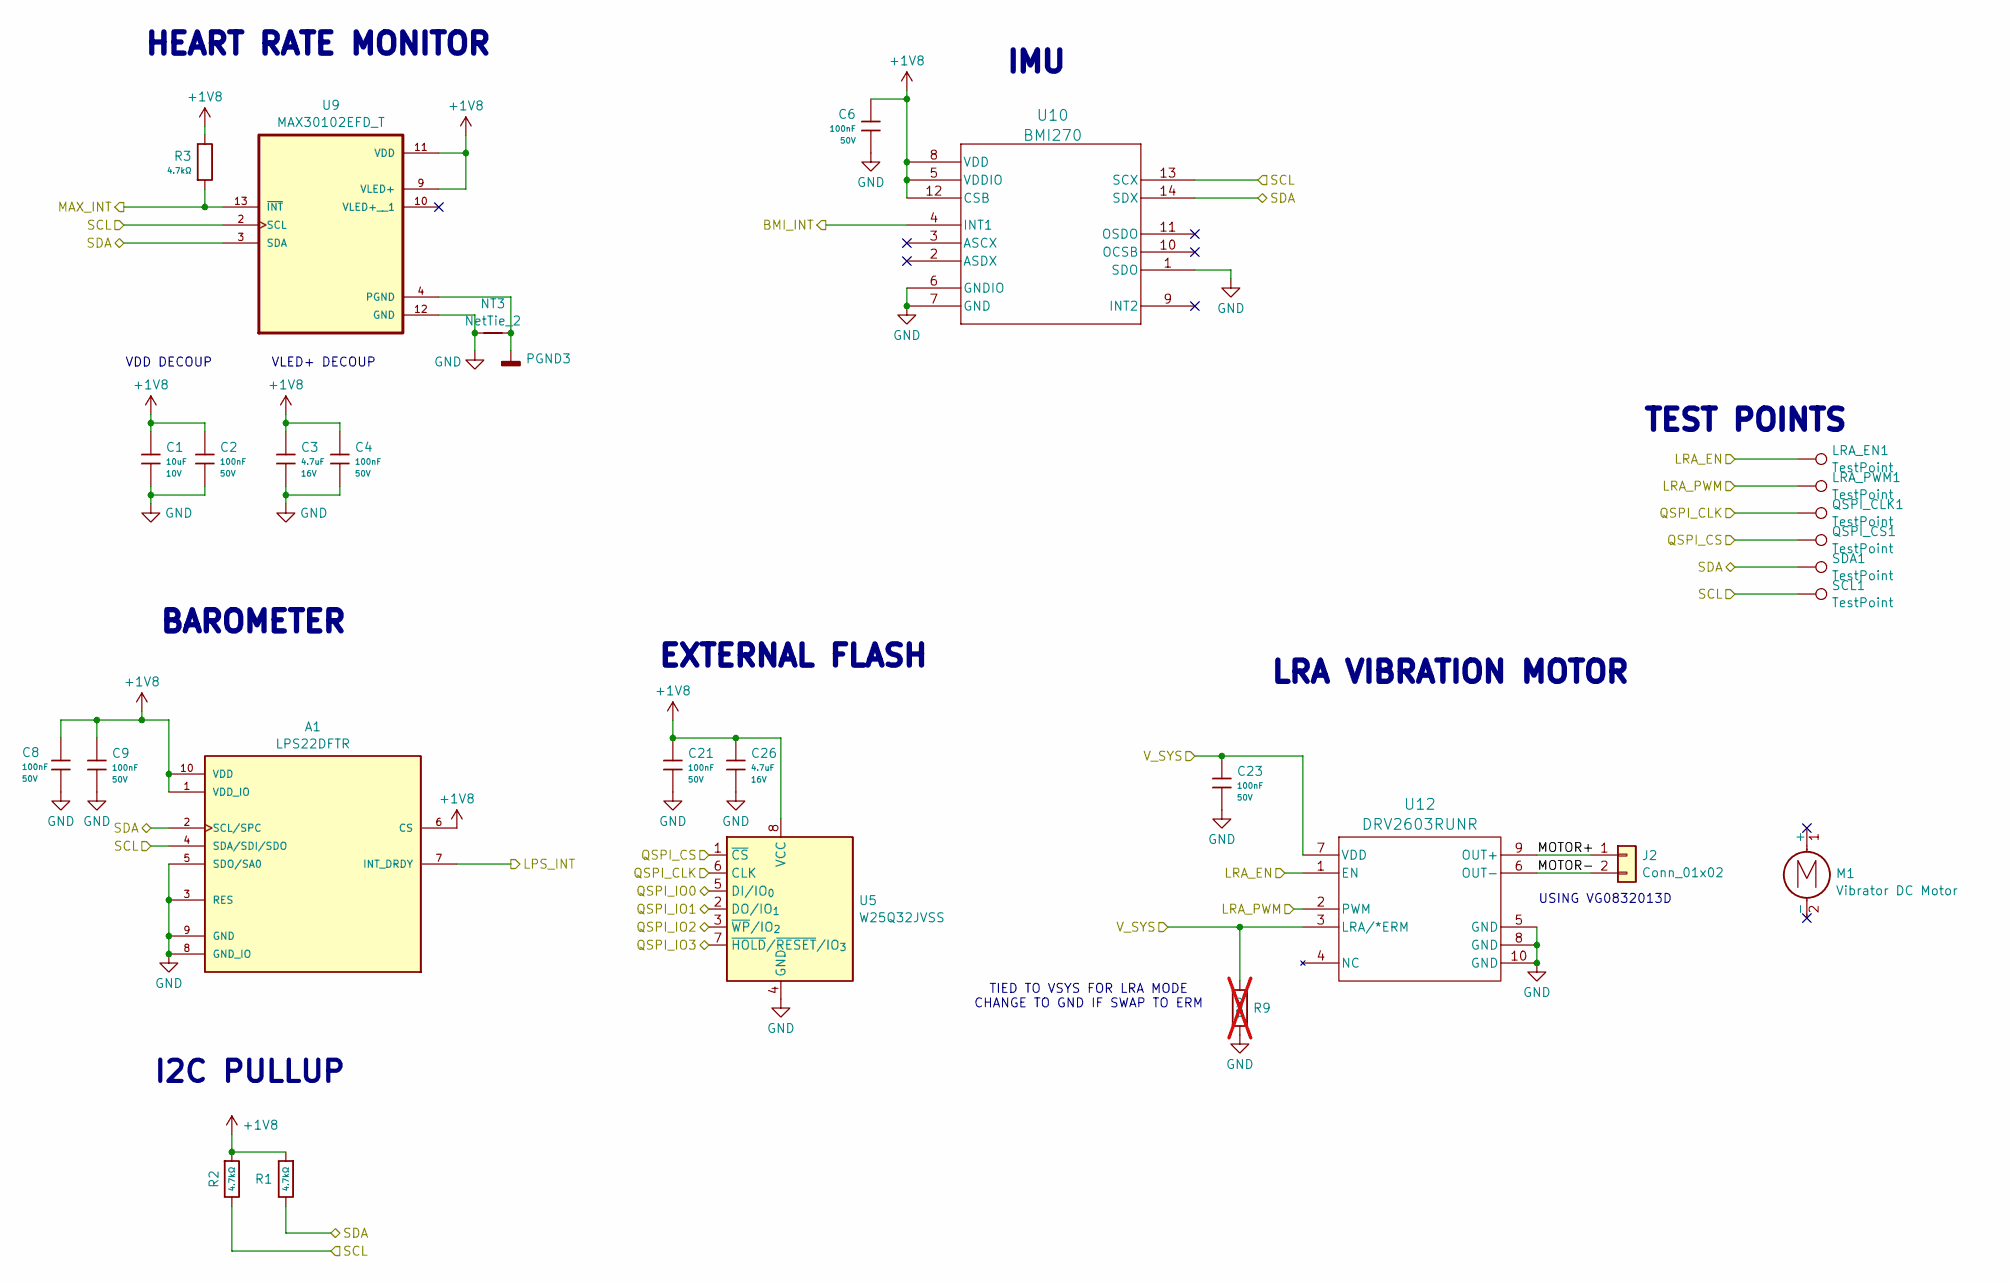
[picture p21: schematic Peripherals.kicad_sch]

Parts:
A1: LPS22DFTR; XDCR_LPS22DFTR; PARTREV 3
C1: 10uF; C_0603; Voltage Rated 10V; Tolerance ±10%; Part CL10A106KP8NNNC; LCSC C19702
C2, C4, C6, C8, C9, C21, C23: 100nF; C_0603; Voltage Rated 50V; Tolerance ±10%; Part CC0603KRX7R9BB104; LCSC C14663
C3, C26: 4.7uF; C_0603; Voltage Rated 16V; Tolerance ±10%; Part CL10A475KO8NNNC; LCSC C19666
J2: Conn_01x02; 1x02_1x1mm
LRA_EN1: TestPoint; TestPoint_Pad_1.0x1.0mm
LRA_PWM1: TestPoint; TestPoint_Pad_1.0x1.0mm
M1: Vibrator DC Motor; digikey# 1670-VC1027B902F-ND
NT3: NetTie_2; NetTie-2_SMD_Pad0.5mm
QSPI_CLK1: TestPoint; TestPoint_Pad_1.0x1.0mm
QSPI_CS1: TestPoint; TestPoint_Pad_1.0x1.0mm
R1, R2, R3: 4.7kΩ; R_0603; Overload Voltage (Max) 75V; Tolerance ±1%; Part 0603WAF4701T5E; LCSC C23162
R9: 10kΩ; R_0402; Overload Voltage (Max) 50V; Tolerance ±1%; Part 0402WGF1002TCE; LCSC C25744; not fitted
SCL1: TestPoint; TestPoint_Pad_1.0x1.0mm
SDA1: TestPoint; TestPoint_Pad_1.0x1.0mm
U5: W25Q32JVSS; SOIC-8_5.3x5.3mm_P1.27mm
U9: MAX30102EFD_T; XDCR_MAX30101EFD_
U10: BMI270; BMI270_BOS-L
U12: DRV2603RUNR; RUN10_TEX

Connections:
+1V8: A1.1 (VDD_IO), A1.6 (CS), A1.10 (VDD), C1.2, C2.2, C3.1, C4.1, C6.1, C8.1, C9.1, C21.1, C26.1, R1.1, R2.1, R3.2, U5.8 (VCC), U9.9 (VLED+), U9.11 (VDD), U10.5 (VDDIO), U10.8 (VDD), U10.12 (CSB); also elsewhere on the board
/Architecture/MCU/BMI_INT: U10.4 (INT1); also elsewhere on the board
/Architecture/MCU/LPS_INT: A1.7 (INT_DRDY); also elsewhere on the board
/Architecture/MCU/LRA_EN: LRA_EN1.1 (1_1), U12.1 (EN); also elsewhere on the board
/Architecture/MCU/LRA_PWM: LRA_PWM1.1 (1_1), U12.2 (PWM); also elsewhere on the board
/Architecture/MCU/MAX_INT: R3.1, U9.13 (~INT); also elsewhere on the board
/Architecture/MCU/QSPI_CLK: QSPI_CLK1.1 (1_1), U5.6 (CLK); also elsewhere on the board
/Architecture/MCU/QSPI_CS: QSPI_CS1.1 (1_1), U5.1 (~CS); also elsewhere on the board
/Architecture/MCU/QSPI_IO0: U5.5 (DI/IO_{0}); also elsewhere on the board
/Architecture/MCU/QSPI_IO1: U5.2 (DO/IO_{1}); also elsewhere on the board
/Architecture/MCU/QSPI_IO2: U5.3 (~WP/IO_{2}); also elsewhere on the board
/Architecture/MCU/QSPI_IO3: U5.7 (~HOLD/~RESET/IO_{3}); also elsewhere on the board
/Architecture/MCU/SCL: A1.4 (SDA/SDI/SDO), R2.2, SCL1.1 (1_1), U9.2 (SCL), U10.13 (SCX); also elsewhere on the board
/Architecture/MCU/SDA: A1.2 (SCL/SPC), R1.2, SDA1.1 (1_1), U9.3 (SDA), U10.14 (SDX); also elsewhere on the board
/Architecture/Peripherals/MOTOR+: J2.1, U12.9 (OUT+)
/Architecture/Peripherals/MOTOR-: J2.2, U12.6 (OUT-)
GND: A1.3 (RES), A1.5 (SDO/SA0), A1.8 (GND_IO), A1.9 (GND), C1.1, C2.1, C3.2, C4.2, C6.2, C8.2, C9.2, C21.2, C23.2, C26.2, NT3.1, R9.2, U5.4 (GND), U9.12 (GND), U10.1 (SDO), U10.6 (GNDIO), U10.7 (GND), U12.5 (GND), U12.8 (GND), U12.10 (GND); also elsewhere on the board
PGND3: NT3.2, U9.4 (PGND)
VSYS: C23.1, R9.1, U12.3 (LRA/*ERM), U12.7 (VDD); also elsewhere on the board

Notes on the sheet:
HEART RATE MONITOR
I2C PULLUP
USING VG0832013D
EXTERNAL FLASH
TIED TO VSYS FOR LRA MODE CHANGE TO GND IF SWAP TO ERM
VDD DECOUP
VLED+ DECOUP
BAROMETER
IMU
TEST POINTS
LRA VIBRATION MOTOR

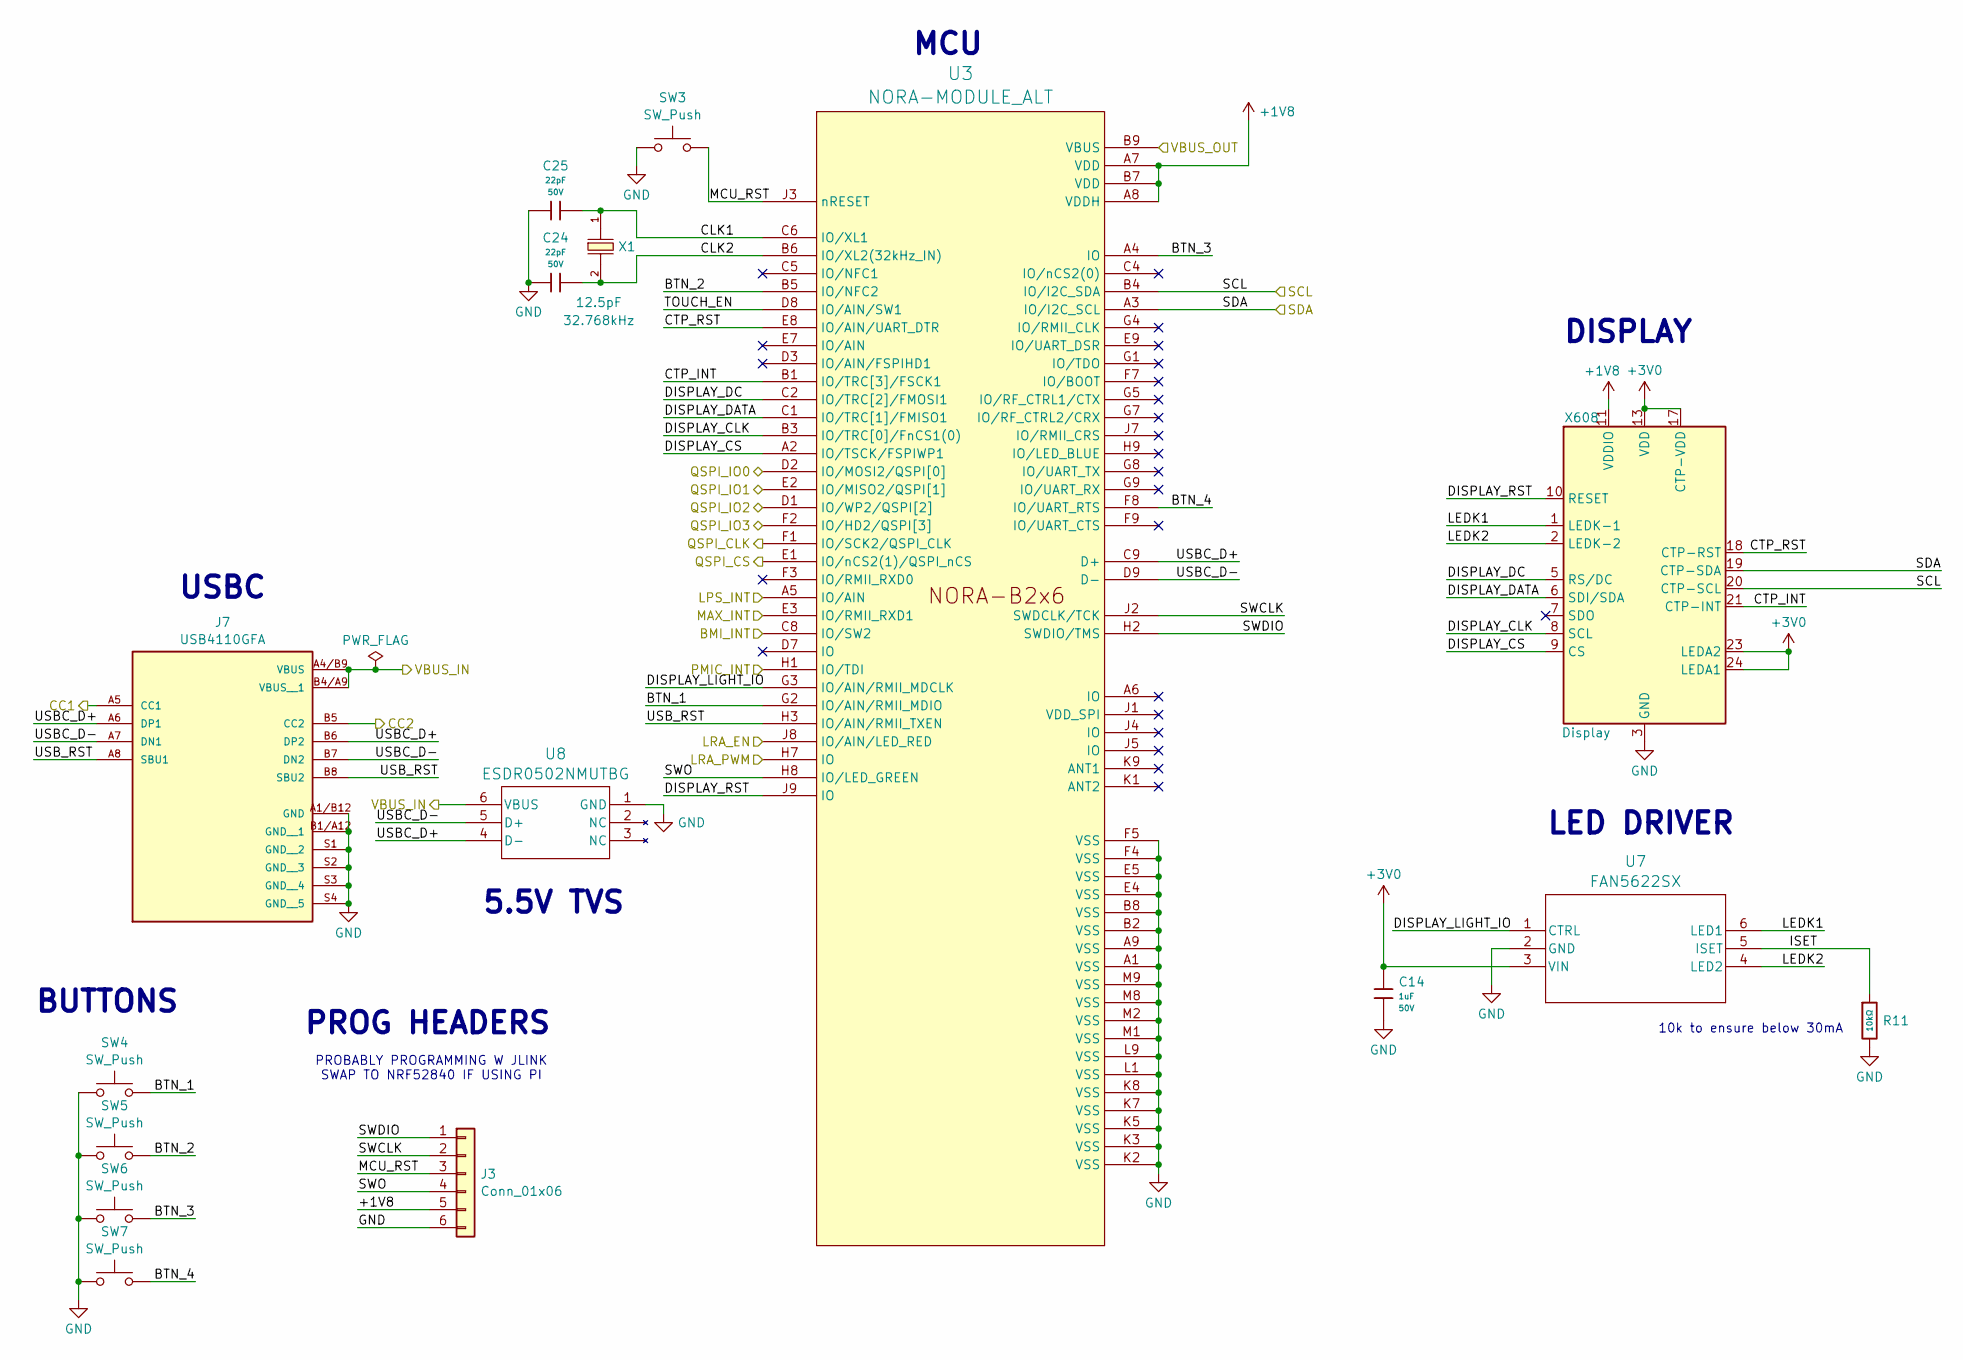
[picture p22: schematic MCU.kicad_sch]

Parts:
C14: 1uF; C_0603; Voltage Rated 50V; Tolerance ±10%; Part CL10A105KB8NNNC; LCSC C15849
C24, C25: 22pF; C_0603; Voltage Rated 50V; Tolerance ±5%; Part CL10C220JB8NNNC; LCSC C1653
J3: Conn_01x06; 2x03_1x1mm
J7: USB4110GFA; GCT_USB4110GFA
R11: 10kΩ; R_0603; Overload Voltage (Max) 75V; Tolerance ±1%; Part 0603WAF1002T5E; LCSC C25804
SW3: SW_Push; R_0805_2012Metric
SW4, SW5, SW6, SW7: SW_Push; SW_Push_1P1T-MP_NO_Horizontal_Alps_SKRTLAE010_3D
U3: NORA-MODULE_ALT; NORA_LGA82R_1430X1040X190_ANT; Manufacturer P/N NORA
U7: FAN5622SX; SSOT6_3X1P7_ONS-L
U8: ESDR0502NMUTBG; UDFN6_517AA_ONS-L
X1: Q13FC1350000400; FC-135R_L3.2-W1.5; Frequency Tolerance ±20ppm; Part Q13FC13500004; LCSC C32346
X608: Display; 24-PIN-ZIF

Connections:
+1V8: J3.5, U3.A7 (VDD), U3.A8 (VDDH), U3.B7 (VDD), X608.11 (VDDIO), X608.12 (VDDIO); also elsewhere on the board
+3V0: C14.1, U7.3 (VIN), X608.13 (VDD), X608.14 (VDD), X608.17 (CTP-VDD), X608.23 (LEDA2), X608.24 (LEDA1); also elsewhere on the board
/Architecture/MCU/BMI_INT: U3.C8 (IO/SW2); also elsewhere on the board
/Architecture/MCU/BTN_1: SW4.2, U3.G2 (IO/AIN/RMII_MDIO)
/Architecture/MCU/BTN_2: SW5.2, U3.B5 (IO/NFC2)
/Architecture/MCU/BTN_3: SW6.2, U3.A4 (IO)
/Architecture/MCU/BTN_4: SW7.2, U3.F8 (IO/UART_RTS)
/Architecture/MCU/CC1: J7.A5 (CC1); also elsewhere on the board
/Architecture/MCU/CC2: J7.B5 (CC2); also elsewhere on the board
/Architecture/MCU/CLK1: C25.2, U3.C6 (IO/XL1), X1.1
/Architecture/MCU/CLK2: C24.2, U3.B6 (IO/XL2(32kHz_IN)), X1.2
/Architecture/MCU/CTP_INT: U3.B1 (IO/TRC[3]/FSCK1), X608.21 (CTP-INT)
/Architecture/MCU/CTP_RST: U3.E8 (IO/AIN/UART_DTR), X608.18 (CTP-RST)
/Architecture/MCU/DISPLAY_CLK: U3.B3 (IO/TRC[0]/FnCS1(0)), X608.8 (SCL)
/Architecture/MCU/DISPLAY_CS: U3.A2 (IO/TSCK/FSPIWP1), X608.9 (CS)
/Architecture/MCU/DISPLAY_DATA: U3.C1 (IO/TRC[1]/FMISO1), X608.6 (SDI/SDA)
/Architecture/MCU/DISPLAY_DC: U3.C2 (IO/TRC[2]/FMOSI1), X608.5 (RS/DC)
/Architecture/MCU/DISPLAY_LIGHT_IO: U3.G3 (IO/AIN/RMII_MDCLK), U7.1 (CTRL)
/Architecture/MCU/DISPLAY_RST: U3.J9 (IO), X608.10 (RESET)
/Architecture/MCU/ISET: R11.1, U7.5 (ISET)
/Architecture/MCU/LEDK1: U7.6 (LED1), X608.1 (LEDK-1)
/Architecture/MCU/LEDK2: U7.4 (LED2), X608.2 (LEDK-2)
/Architecture/MCU/LPS_INT: U3.A5 (IO/AIN); also elsewhere on the board
/Architecture/MCU/LRA_EN: U3.J8 (IO/AIN/LED_RED); also elsewhere on the board
/Architecture/MCU/LRA_PWM: U3.H7 (IO); also elsewhere on the board
/Architecture/MCU/MAX_INT: U3.E3 (IO/RMII_RXD1); also elsewhere on the board
/Architecture/MCU/MCU_RST: J3.3, SW3.2, U3.J3 (nRESET)
/Architecture/MCU/PMIC_INT: U3.H1 (IO/TDI); also elsewhere on the board
/Architecture/MCU/QSPI_CLK: U3.F1 (IO/SCK2/QSPI_CLK); also elsewhere on the board
/Architecture/MCU/QSPI_CS: U3.E1 (IO/nCS2(1)/QSPI_nCS); also elsewhere on the board
/Architecture/MCU/QSPI_IO0: U3.D2 (IO/MOSI2/QSPI[0]); also elsewhere on the board
/Architecture/MCU/QSPI_IO1: U3.E2 (IO/MISO2/QSPI[1]); also elsewhere on the board
/Architecture/MCU/QSPI_IO2: U3.D1 (IO/WP2/QSPI[2]); also elsewhere on the board
/Architecture/MCU/QSPI_IO3: U3.F2 (IO/HD2/QSPI[3]); also elsewhere on the board
/Architecture/MCU/SCL: U3.B4 (IO/I2C_SDA), X608.20 (CTP-SCL); also elsewhere on the board
/Architecture/MCU/SDA: U3.A3 (IO/I2C_SCL), X608.19 (CTP-SDA); also elsewhere on the board
/Architecture/MCU/SWCLK: J3.2, U3.J2 (SWDCLK/TCK)
/Architecture/MCU/SWDIO: J3.1, U3.H2 (SWDIO/TMS)
/Architecture/MCU/SWO: J3.4, U3.H8 (IO/LED_GREEN)
/Architecture/MCU/TOUCH_EN: U3.D8 (IO/AIN/SW1)
/Architecture/MCU/USBC_D+: J7.A6 (DP1), J7.B6 (DP2), U3.C9 (D+), U8.4 (D-)
/Architecture/MCU/USBC_D-: J7.A7 (DN1), J7.B7 (DN2), U3.D9 (D-), U8.5 (D+)
/Architecture/MCU/USB_RST: J7.A8 (SBU1), J7.B8 (SBU2), U3.H3 (IO/AIN/RMII_TXEN)
/Architecture/MCU/VBUS_IN: J7.A4/B9 (VBUS), J7.B4/A9 (VBUS__1), U8.6 (VBUS); also elsewhere on the board
/Architecture/MCU/VBUS_OUT: U3.B9 (VBUS); also elsewhere on the board
GND: C14.2, C24.1, C25.1, J3.6, J7.A1/B12 (GND), J7.B1/A12 (GND__1), J7.S1 (GND__2), J7.S2 (GND__3), J7.S3 (GND__4), J7.S4 (GND__5), R11.2, SW3.1, SW4.1, SW5.1, SW6.1, SW7.1, U3.A1 (VSS), U3.A9 (VSS), U3.B2 (VSS), U3.B8 (VSS), U3.E4 (VSS), U3.E5 (VSS), U3.F4 (VSS), U3.F5 (VSS), U3.K2 (VSS), U3.K3 (VSS), U3.K5 (VSS), U3.K7 (VSS), U3.K8 (VSS), U3.L1 (VSS), U3.L9 (VSS), U3.M1 (VSS), U3.M2 (VSS), U3.M8 (VSS), U3.M9 (VSS), U7.2 (GND), U8.1 (GND), X608.3 (GND), X608.4 (GND), X608.15 (GND), X608.16 (GND); also elsewhere on the board

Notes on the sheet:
BUTTONS
DISPLAY
5.5V TVS
USBC
LED DRIVER
10k to ensure below 30mA
MCU
PROBABLY PROGRAMMING W JLINK SWAP TO NRF52840 IF USING PI
PROG HEADERS

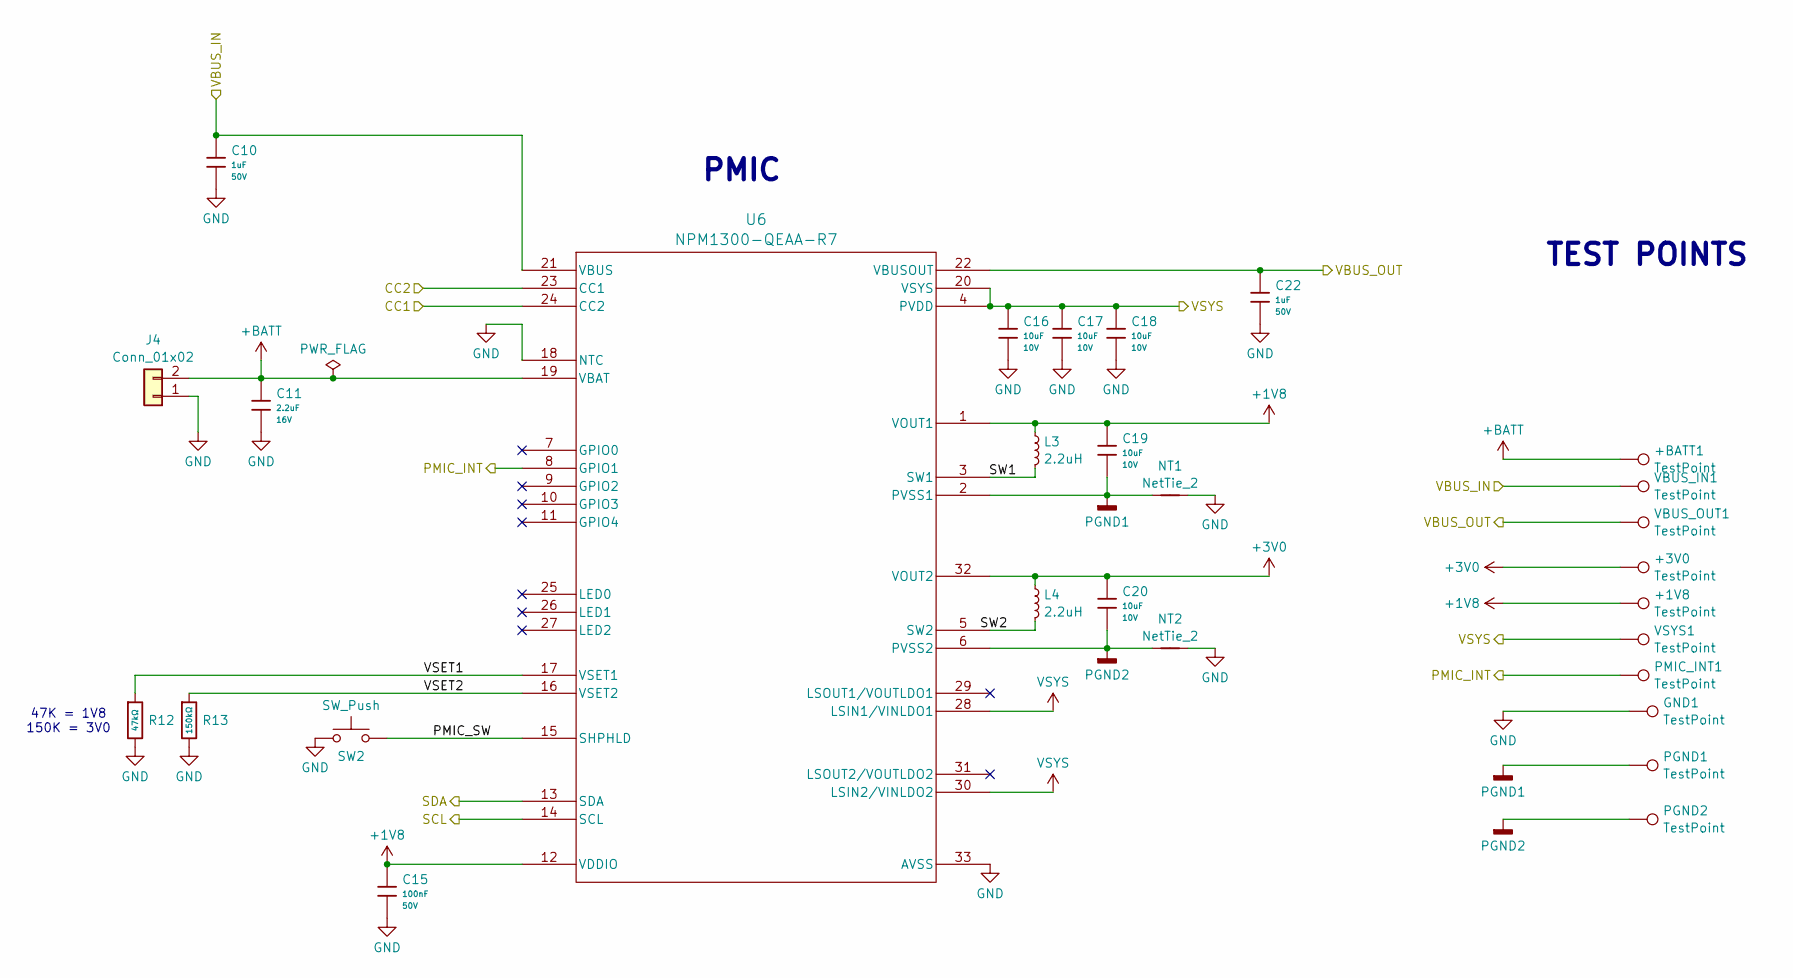
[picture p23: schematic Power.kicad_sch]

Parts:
+1V8, +3V0: TestPoint; TestPoint_Pad_1.0x1.0mm
+BATT1: TestPoint; TestPoint_Pad_1.0x1.0mm
C10, C22: 1uF; C_0603; Voltage Rated 50V; Tolerance ±10%; Part CL10A105KB8NNNC; LCSC C15849
C11: 2.2uF; C_0603; Voltage Rated 16V; Tolerance ±10%; Part CL10A225KO8NNNC; LCSC C23630
C15: 100nF; C_0603; Voltage Rated 50V; Tolerance ±10%; Part CC0603KRX7R9BB104; LCSC C14663
C16, C17, C18, C19, C20: 10uF; C_0603; Voltage Rated 10V; Tolerance ±10%; Part CL10A106KP8NNNC; LCSC C19702
GND1: TestPoint; TestPoint_Pad_1.0x1.0mm
J4: Conn_01x02; MOLEX_0781710002
L3, L4: 2.2uH; L_0805_2012Metric; Part DFE201612E-2R2M=P2
NT1, NT2: NetTie_2; NetTie-2_SMD_Pad0.5mm
PGND1, PGND2: TestPoint; TestPoint_Pad_1.0x1.0mm
PMIC_INT1: TestPoint; TestPoint_Pad_1.0x1.0mm
R12: 47kΩ; R_0603; Overload Voltage (Max) 75V; Tolerance ±1%; Part 0603WAF4702T5E; LCSC C25819
R13: 150kΩ; R_0603; Overload Voltage (Max) 75V; Tolerance ±1%; Part 0603WAF1503T5E; LCSC C22807
SW2: SW_Push; R_0805_2012Metric
U6: NPM1300-QEAA-R7; QFN32_5X5_NOR-L
VBUS_IN1: TestPoint; TestPoint_Pad_1.0x1.0mm
VBUS_OUT1: TestPoint; TestPoint_Pad_1.0x1.0mm
VSYS1: TestPoint; TestPoint_Pad_1.0x1.0mm

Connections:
+1V8: +1V8.1 (1_1), C15.1, C19.1, L3.1, U6.1 (VOUT1), U6.12 (VDDIO); also elsewhere on the board
+3V0: +3V0.1 (1_1), C20.1, L4.1, U6.32 (VOUT2); also elsewhere on the board
+BATT: +BATT1.1 (1_1), C11.1, J4.2, U6.19 (VBAT)
/Architecture/MCU/CC1: U6.24 (CC2); also elsewhere on the board
/Architecture/MCU/CC2: U6.23 (CC1); also elsewhere on the board
/Architecture/MCU/PMIC_INT: PMIC_INT1.1 (1_1), U6.8 (GPIO1); also elsewhere on the board
/Architecture/MCU/SCL: U6.14 (SCL); also elsewhere on the board
/Architecture/MCU/SDA: U6.13 (SDA); also elsewhere on the board
/Architecture/MCU/VBUS_IN: C10.1, U6.21 (VBUS), VBUS_IN1.1 (1_1); also elsewhere on the board
/Architecture/MCU/VBUS_OUT: C22.1, U6.22 (VBUSOUT), VBUS_OUT1.1 (1_1); also elsewhere on the board
/Architecture/Power/PMIC_SW: SW2.2, U6.15 (SHPHLD)
/Architecture/Power/SW1: L3.2, U6.3 (SW1)
/Architecture/Power/SW2: L4.2, U6.5 (SW2)
/Architecture/Power/VSET1: R12.1, U6.17 (VSET1)
/Architecture/Power/VSET2: R13.1, U6.16 (VSET2)
GND: C10.2, C11.2, C15.2, C16.2, C17.2, C18.2, C22.2, GND1.1 (1_1), J4.1, NT1.2, NT2.2, R12.2, R13.2, SW2.1, U6.18 (NTC), U6.33 (AVSS); also elsewhere on the board
PGND1: C19.2, NT1.1, PGND1.1 (1_1), U6.2 (PVSS1)
PGND2: C20.2, NT2.1, PGND2.1 (1_1), U6.6 (PVSS2)
VSYS: C16.1, C17.1, C18.1, U6.4 (PVDD), U6.20 (VSYS), U6.28 (LSIN1/VINLDO1), U6.30 (LSIN2/VINLDO2), VSYS1.1 (1_1); also elsewhere on the board

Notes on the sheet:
TEST POINTS
47K = 1V8 150K = 3V0
PMIC

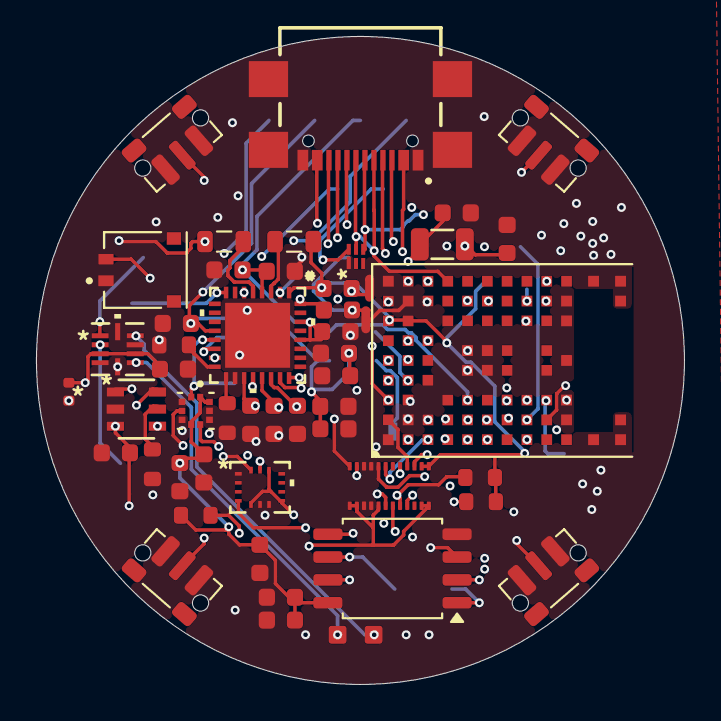
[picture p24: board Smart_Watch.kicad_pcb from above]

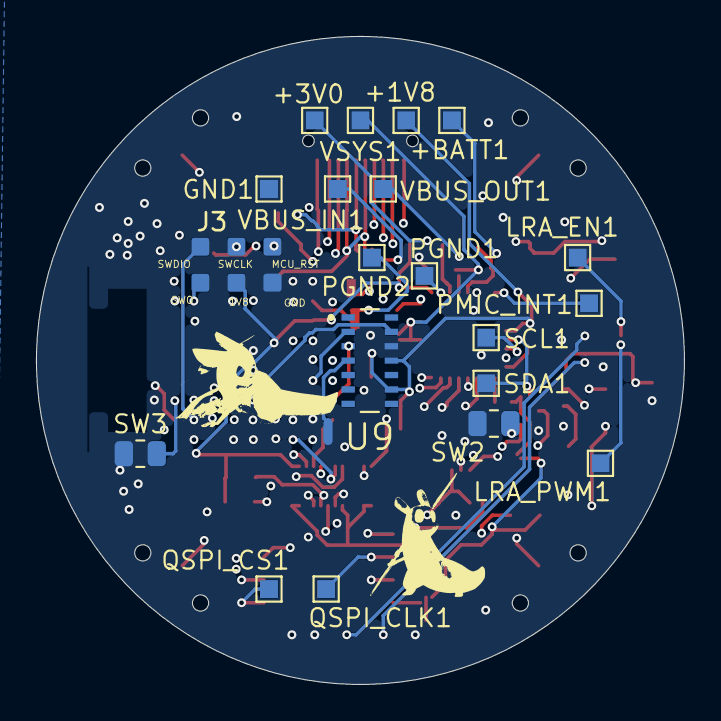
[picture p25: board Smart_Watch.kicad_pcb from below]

Board: 4 copper layers, 36.0 x 36.0 mm, 71 parts (21 on the bottom side), 57 nets.

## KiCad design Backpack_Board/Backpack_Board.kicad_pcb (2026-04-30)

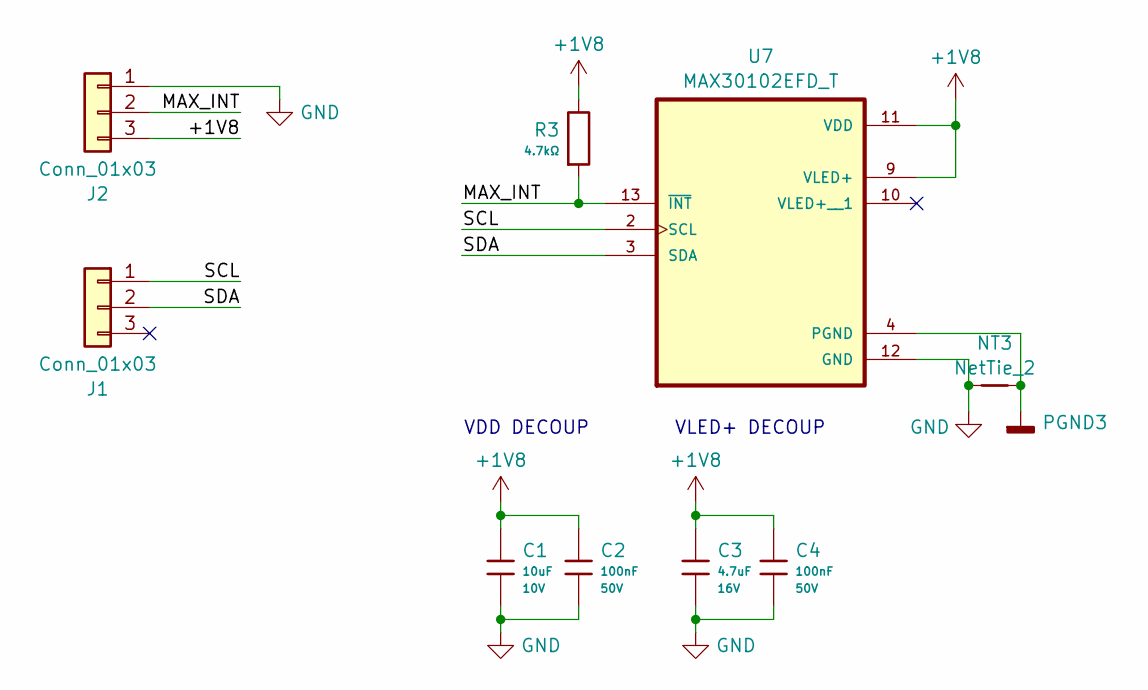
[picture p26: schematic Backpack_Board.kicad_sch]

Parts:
C1: 10uF; C_0603; Voltage Rated 10V; Tolerance ±10%; Part CL10A106KP8NNNC; LCSC C19702
C2, C4: 100nF; C_0603; Voltage Rated 50V; Tolerance ±10%; Part CC0603KRX7R9BB104; LCSC C14663
C3: 4.7uF; C_0603; Voltage Rated 16V; Tolerance ±10%; Part CL10A475KO8NNNC; LCSC C19666
J1, J2: Conn_01x03; PinHeader_1x03_P1.27mm_Vertical
NT3: NetTie_2; NetTie-2_SMD_Pad0.5mm
R3: 4.7kΩ; R_0603; Overload Voltage (Max) 75V; Tolerance ±1%; Part 0603WAF4701T5E; LCSC C23162
U7: MAX30102EFD_T; XDCR_MAX30101EFD_

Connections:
+1V8: C1.2, C2.2, C3.1, C4.1, J2.3, R3.2, U7.9 (VLED+), U7.11 (VDD)
/MAX_INT: J2.2, R3.1, U7.13 (~INT)
/SCL: J1.1, U7.2 (SCL)
/SDA: J1.2, U7.3 (SDA)
GND: C1.1, C2.1, C3.2, C4.2, J2.1, NT3.1, U7.12 (GND)
PGND3: NT3.2, U7.4 (PGND)

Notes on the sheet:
VLED+ DECOUP
VDD DECOUP

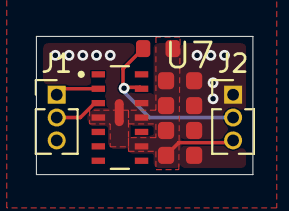
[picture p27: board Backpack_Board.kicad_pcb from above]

Board: 2 copper layers, 12.0 x 7.7 mm, 9 parts (0 on the bottom side), 6 nets.

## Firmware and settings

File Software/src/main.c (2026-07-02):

#include <zephyr/kernel.h>
#include <zephyr/device.h>
#include <zephyr/logging/log.h>

#include "activity.h"
#include "app_settings.h"
#include "backlight.h"
#include "ble_media.h"
#include "buttons.h"
#include "display_ui.h"
#include "heart_rate.h"
#include "haptics.h"
#include "power.h"
#include "power_manager.h"

LOG_MODULE_REGISTER(smart_watch, LOG_LEVEL_INF);

#define LOG_DEVICE_READY(node_id, name)                                            \
	do {                                                                       \
		const struct device *const dev = DEVICE_DT_GET(node_id);           \
		LOG_INF("%s: %s", name, device_is_ready(dev) ? "ready" : "not ready"); \
	} while (false)

int main(void)
{
	int err;

	LOG_INF("Custom smartwatch firmware starting");

	LOG_DEVICE_READY(DT_NODELABEL(pmic), "nPM1300");
	LOG_DEVICE_READY(DT_NODELABEL(pmic_charger), "nPM1300 charger");
	LOG_DEVICE_READY(DT_NODELABEL(bmi270), "BMI270");
	LOG_DEVICE_READY(DT_NODELABEL(max30102), "MAX30102");
	LOG_DEVICE_READY(DT_NODELABEL(lps22df), "LPS22DF");
	LOG_DEVICE_READY(DT_NODELABEL(display), "GC9A01");
	LOG_DEVICE_READY(DT_NODELABEL(w25q32), "W25Q32");

	err = backlight_init(false);
	if (err != 0) {
		LOG_ERR("Backlight init failed (%d)", err);
	}

	err = haptics_init();
	if (err != 0) {
		LOG_ERR("Haptics init failed (%d)", err);
	}

	err = app_settings_init();
	if (err != 0) {
		LOG_ERR("User settings init failed (%d)", err);
	}

	err = ble_media_init();
	if (err != 0) {
		LOG_ERR("BLE media init failed (%d)", err);
	}

	err = buttons_init();
	if (err != 0) {
		LOG_ERR("Button service init failed (%d)", err);
	}

	err = activity_init();
	if (err != 0) {
		LOG_ERR("Activity tracking init failed (%d)", err);
	}

	err = heart_rate_init();
	if (err != 0) {
		LOG_ERR("Heart-rate service init failed (%d)", err);
	}

	err = power_init();
	if (err != 0) {
		LOG_ERR("Power telemetry init failed (%d)", err);
	}

	err = display_ui_init();
	if (err != 0) {
		LOG_ERR("Display UI init failed (%d)", err);
	}

	err = power_manager_init();
	if (err != 0) {
		LOG_ERR("Power manager init failed (%d)", err);
	}

	return 0;
}

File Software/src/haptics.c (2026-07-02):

/*
 * SPDX-License-Identifier: Apache-2.0
 */

#include "haptics.h"

#include <errno.h>
#include <stdbool.h>
#include <stdint.h>

#include <zephyr/device.h>
#include <zephyr/drivers/gpio.h>
#include <zephyr/drivers/pwm.h>
#include <zephyr/kernel.h>
#include <zephyr/logging/log.h>

LOG_MODULE_REGISTER(haptics, LOG_LEVEL_INF);

#define HAPTIC_EN_NODE DT_NODELABEL(haptic_en)
#define HAPTIC_PWM_NODE DT_NODELABEL(haptic_pwm)

static const struct gpio_dt_spec haptic_en = GPIO_DT_SPEC_GET(HAPTIC_EN_NODE, gpios);
static const struct pwm_dt_spec haptic_pwm = PWM_DT_SPEC_GET(HAPTIC_PWM_NODE);
static bool haptics_ready;

static int haptics_apply(uint32_t pulse_ns, bool enable)
{
	int err = pwm_set_dt(&haptic_pwm, haptic_pwm.period, pulse_ns);

	if (err != 0) {
		LOG_ERR("Haptic PWM update failed (%d)", err);
		return err;
	}

	err = gpio_pin_set_dt(&haptic_en, enable ? 1 : 0);
	if (err != 0) {
		LOG_ERR("Haptic enable update failed (%d)", err);
	}

	return err;
}

static void haptic_stop_work_handler(struct k_work *work)
{
	ARG_UNUSED(work);

	(void)haptics_apply(0U, false);
}

K_WORK_DELAYABLE_DEFINE(haptic_stop_work, haptic_stop_work_handler);

int haptics_init(void)
{
	int err;

	if (!gpio_is_ready_dt(&haptic_en)) {
		LOG_ERR("Haptic enable GPIO is not ready");
		return -ENODEV;
	}

	if (!pwm_is_ready_dt(&haptic_pwm)) {
		LOG_ERR("Haptic PWM device is not ready");
		return -ENODEV;
	}

	err = gpio_pin_configure_dt(&haptic_en, GPIO_OUTPUT_INACTIVE);
	if (err != 0) {
		LOG_ERR("Haptic enable configure failed (%d)", err);
		return err;
	}

	err = haptics_apply(0U, false);
	if (err != 0) {
		return err;
	}

	haptics_ready = true;
	LOG_INF("Haptics ready: period %u ns", haptic_pwm.period);
	return 0;
}

int haptics_pulse(uint16_t duration_ms, uint8_t intensity_percent)
{
	uint32_t pulse_ns;
	int err;

	if (!haptics_ready) {
		return -ENODEV;
	}

	if ((duration_ms == 0U) || (intensity_percent == 0U)) {
		return haptics_stop();
	}

	if (intensity_percent > 100U) {
		intensity_percent = 100U;
	}

	pulse_ns = (uint32_t)(((uint64_t)haptic_pwm.period * intensity_percent) / 100U);

	err = haptics_apply(pulse_ns, true);
	if (err != 0) {
		return err;
	}

	err = k_work_reschedule(&haptic_stop_work, K_MSEC(duration_ms));
	if (err < 0) {
		(void)haptics_apply(0U, false);
		LOG_ERR("Haptic stop scheduling failed (%d)", err);
		return err;
	}

	return 0;
}

int haptics_stop(void)
{
	if (!haptics_ready) {
		return -ENODEV;
	}

	(void)k_work_cancel_delayable(&haptic_stop_work);
	return haptics_apply(0U, false);
}

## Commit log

2026-04-08 Worked on peripheral schem
    [Peripherals.kicad_sch, Smart_Watch.kicad_sch]
2026-04-08 Added flash
    [Peripherals.kicad_sch]
2026-04-09 Updated power and MCU schem
    [MCU.kicad_sch, Power.kicad_sch, Smart_Watch.kicad_sch]
2026-04-11 PMIC integration
    [Power.kicad_sch, Smart_Watch.kicad_sch]
2026-04-12 Updated MCU
    [MCU.kicad_sch, Peripherals.kicad_sch, Power.kicad_sch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]
2026-04-13 Fixed Hierarchical Labels
    [Architecture.kicad_sch, MCU.kicad_sch, Peripherals.kicad_sch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]
2026-04-14 Added Vibration Motor & Prog Pinout
    [Architecture.kicad_sch, MCU.kicad_sch, Peripherals.kicad_sch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]
2026-04-16 Added clock and updated schem
    [Architecture.kicad_sch, MCU.kicad_sch, Peripherals.kicad_sch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]
2026-04-21 Updated Schem and Organized Layout
    [Architecture.kicad_sch, B2B-PH-SM4-TB.STEP, IND_LQM2HPN2R2MG0L_MUR.step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]
2026-04-25 Layout V1
    [MCU.kicad_sch, Peripherals.kicad_sch, Power.kicad_sch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]
2026-04-27 I hate you git
    [Smart_Watch.kicad_pcb]
2026-04-28 Update most sym/footprint libraries
    [Architecture.kicad_sch, MCU.kicad_sch, NORA-B106-00B.step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]
2026-04-28 Remove remaining .kicad_prl files
2026-04-29 Added Backpack Board
    [Backpack_Board.kicad_pcb, Backpack_Board.kicad_sch]
2026-04-29 Switch inductors
    [Power.kicad_sch, Smart_Watch.kicad_pcb]
2026-04-29 Change more footprints
    [MCU.kicad_sch, Smart_Watch.kicad_pcb]
2026-04-29 WIP changes
    [MCU.kicad_sch, Power.kicad_sch, Smart_Watch.kicad_pcb]
2026-04-29 Completed Backpack Board
    [Backpack_Board.kicad_pcb, Backpack_Board.kicad_sch]
2026-04-29 Remove heart rate sensor from main board
    [Peripherals.kicad_sch, Smart_Watch.kicad_pcb]
2026-04-29 Update the last components and change a couple
    [MCU.kicad_sch, Smart_Watch.kicad_pcb]
2026-04-29 Added Backpack Integration + Layout V1
    [MCU.kicad_sch, Peripherals.kicad_sch, Power.kicad_sch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]
2026-04-29 Layout Midpoint, Updated Backpack Schem
    [Backpack_Board.kicad_sch, Peripherals.kicad_sch, Smart_Watch.kicad_pcb]
2026-04-29 USB Layout Updates
    [Smart_Watch.kicad_pcb]
2026-04-30 Routing V1 Complete!
    [Smart_Watch.kicad_pcb]
2026-04-30 PCB V1 Complete!
    [Smart_Watch.kicad_pcb]
2026-04-30 Updated Keepout and Started Case Model
    [Backpack_Board.kicad_pcb, Backpack_Board.kicad_sch, Backpack_Board.step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]
2026-05-01 Began Backpack Removal to Lower Profile
    [MCU.kicad_sch, Peripherals.kicad_sch, Power.kicad_sch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]
2026-05-01 Flipped switches + Heart Rate, Moving Battery
    [Power.kicad_sch, Smart_Watch.kicad_pcb]
2026-05-01 Everything but ZIF moved
    [Smart_Watch.kicad_pcb]
2026-05-01 Everything Moved to Front
    [Backpack_Board.kicad_pcb, Backpack_Board.kicad_sch, Backpack_Board.step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]
2026-05-01 Restore deleted files
    [Backpack_Board.kicad_pcb, Backpack_Board.kicad_sch, Backpack_Board.step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]
2026-05-01 Restored Too Many Files D:
    [IND_LQM2HPN2R2MG0L_MUR.step, NORA-B106-00B.step, QFN32_5X5_NOR.step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]
2026-05-01 Updated ZIF Keepout & Cleaned Trace Routing
    [Smart_Watch.kicad_pcb]
2026-05-04 Edited Switch & MCU Location to Fit Case
    [Smart_Watch.kicad_pcb]
2026-05-05 Added Test Points and Changed to Top Mounted USBC
    [MCU.kicad_sch, Peripherals.kicad_sch, Power.kicad_sch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]
2026-05-07 Small Updates
    [Smart_Watch.kicad_pcb]
2026-05-07 Fix some ERC problems
    [MCU.kicad_sch, Peripherals.kicad_sch, Power.kicad_sch]
2026-05-07 New Case Files + Updated DRC Errors
    [HD-LA0503-LW28.step, MCU.kicad_sch, Peripherals.kicad_sch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]
2026-05-17 Replaced unavailable JLC components
    [Peripherals.kicad_sch, Smart_Watch.kicad_pcb]
2026-05-18 Updated DRC Errors & More JLC Changes
    [Peripherals.kicad_sch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]
2026-05-21 Replaced b106 w b206 for jlc compatibility
    [Backpack_Board.step, MCU.kicad_sch, VG0832013D.STEP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]
2026-05-21 Updated Layout for B206
    [Smart_Watch.kicad_pcb]
2026-05-25 Updated Layout
    [Smart_Watch.kicad_pcb]
2026-05-26 Swapped back to smaller Barometer + IMU
    [Peripherals.kicad_sch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]
2026-05-29 Removed amb light, extended board for usbc and buttons
    [Architecture.kicad_sch, MCU.kicad_sch, Peripherals.kicad_sch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]
2026-06-05 Everything fits on front!
    [Smart_Watch.kicad_pcb]
2026-07-02 Charger Telem & Heart Rate Monitor Driver
2026-07-02 Enabled NPM charging, added settings for haptics
